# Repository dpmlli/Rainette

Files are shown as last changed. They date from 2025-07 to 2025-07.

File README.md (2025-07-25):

# Rainette

The ***Rainette*** project carried out as part of the Bachelor thesis at HEIG-VD. The
project involves designing an electronic board capable of collecting measurements
and controlling actuators to regulate an aquaponic greenhouse. It is an embedded
system that communicates wirelessly with a central unit and can operate on battery
power. The work includes the phases of preliminary analysis, hardware and software
design, as well as commissioning.

## Content

The repository contains 3 folders: `DOC`, `HW`, and `SW`.

- **DOC** : contains the project documentation. This includes :
    * Some elements specific to the *Rainette* PCB
    * The final report and the specifications
    * The logbook and planning documents
- **HW**  : contains the *Altium* projects for the *Rainette* and *STM32WB5MM-DK* boards.
- **SW**  : contains all the project code. This includes :
    * The firmware for the *Rainette* and *Disco (STM32WB5MM-DK)* boards
    * The programs for the *Raspberry Pi*
    * The simulation scripts

## Script instructions

### Mbed OS

To set up the code for the *Rainette* and *Disco* boards :
- Retrieve the contents of the `Mbed OS` folder and add the `mbed-os` folder from the following repository: https://github.com/ARMmbed/mbed-os. To reproduce the environment in which the project was developed, the following *VSCode* extensions must be installed : `C/C++ Tools`, `Task Runner`, `Cortex-Debug`, and `Copy file name`. You also need to install Mercurial, Mbed CLI, and the dependencies listed in the `requirements.txt` file. More details here : https://github.com/YannCharbon/vscode-mbed-env.  
- Then add the files from either the `Rainette` or `Disco` folders.
- Update the firmware of the Cortex-M0+ using the `STM32CubeProgrammer` software. Use the binary `stm32wb5x_BLE_HCILayer_fw.bin`, version 1.12.0 (additional instructions can be found in the report).
- Compile the program.
- For the *Disco* board, the binary can be flashed directly from *VSCode*. With the *Rainette* board, it must be done using the `STM32CubeProgrammer` software following these steps :
    1. Connect to the board
    2. *FUS* tab: Update the firmware using the following binary `stm32wb5x_BLE_HCILayer_fw.bin`, version 1.12.0 (`M0+ FW` folder)
    3. *FUS* tab: Click the `Start Wireless Stack` button
    4. *Erasing & Programming* tab: Start programming using the *Rainette* binary

### GUI

The `rainette_GUI.py` and `disco_GUI.py` scripts require the following Python libraries: `bleak` and `pyside6`. Python version 3.11 was used, but the scripts should work with earlier versions as well.

Once *advertising* is enabled by the *BLE* server, wait 2–3 seconds before running the script. The window will appear if the server is successfully detected by the client.

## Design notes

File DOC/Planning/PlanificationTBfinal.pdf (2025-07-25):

Étapes | Tâches
Échéances
Début du projet | Analyse fonctionnelle du projet, recherches sur le sujet Planification Définition du cahier des charges

Hardware
Objectifs, contraintes, choix principaux, budget

Schéma : connexions externes

Schéma : analyse fonctionnelle

Schéma : choix des composants

Schéma : finalisation

PCB : placement des composants

PCB : routage

PCB : assemblage et dépannage

## Planification TB Pomelli

Software
Module : communications entre les devkits

Module : prise en main et installation bibliothèques

Modules : tests individuels des éléments

Modules : programmation du main et dépannage

Rapsberry PI : prise en main et installation bibliothèques

Raspberry PI : programmation du main et dépannage

Tests et validation
Tests entre modules et Raspberry PI

Heures planifiées
Heures effectuées

Heures (plan./effe.) | Semaine 1 | Semaine 2 | Semaine 3 | Semaine 4 | Semaine 5
| | | ven. 7.3
| | | CdC
35 | | | FIN | | C

### 28 R 30 U 4 N 2 C 4 H

3
168

### 12 C 15 R 12 U 3 N 24 C 20 H

24
40

### 24 C 49 R 12 U 20 N 24 C 18 H

24

Février | Mars

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
Semaine 6 | Semaine 7 | Semaine 8 | Semaine 9 | Vacances | Semaine 10 | Semaine 11

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
Avril

PÂQUESPÂQUES

Semaine 12 | Semaine 13 | Semaine 14 | Semaine 15 | Semaine 16 | Semaine 17 | Semaine 18
| | | | ven. 13.6 Rendu inter.

FIN

Mai | Juin

Semaine 19 | Semaine 20 | Semaine 21 | Semaine 22 | Semaine 23 | Semaine 24 | Semaine 25
| | | ven. 25.7 Rendu fin.
Juillet | Août

FIN

FIN

Semaine 26 Semaine 27
lun. 18.8
Affiche

Août

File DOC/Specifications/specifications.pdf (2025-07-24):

## Module de commande de serre aquaponique Cahier des charges - Version 0

### Damien Pomelli

### March 27, 2025

## 1 Descriptif

Le projet consiste en la réalisation d’éléments électroniques permettant l’automatisation et la surveillance d’une serre aquaponique ou hydronique. Ce type de serre est composé d’un circuit d’eau fermé pouvant contenir un écosystème, raison pour laquelle il est nécessaire de pouvoir mesurer les grandeurs physiques cruciales telles que la température de l’eau ou le taux de pH.
Le travail de Bachelor se compose en deux grandes phases. La première consiste en la réalisation d’une carte électronique capable de collecter des données de différents capteurs et de pouvoir les envoyer vers une unité centrale. Cette carte doit pouvoir fonctionner sur pile et/ou par alimentation filaire. La communication avec l’unité centrale doit se faire au moyen d’un protocole sans fil. Le développement de la carte doit être axé sur la basse consommation pour le fonctionnement sur pile. La carte doit être capable de lire des valeurs analogiques au moyen d’un ADC mais elle ne contient pas d’interface spécifique à une sonde en particulier. La carte doit également être en mesure de piloter des actionneurs.
La seconde partie du travail est dédiée à la programmation de cette carte. Elle doit être en mesure de transmettre les données récoltées par les capteurs et d’activer des actionneurs si une commande lui est transmise. Il est également demandé de programmer l’unité centrale afin qu’elle puisse communiquer avec la/les carte/s électroniques. Il n’est pas prévu de réaliser la gestion globale de la serre sur l’unité centrale, simplement de s’assurer que la communication fonctionne correctement.

1

## 2 Objectifs

Les objectifs de ce projet sont les suivants :

- Mener le projet en documentant l’avancement. Identifier et expliquer les raisons et solutions à apporter en cas d’incapacité à remplir un objectif fixé.
- Concevoir une carte électronique sous forme de prototype selon les critères suivants.
1. Doit pouvoir fonctionner sur pile et/ou par alimentation filaire.
2. Doit pouvoir collecter des données provenant d’un capteur.
3. Doit pouvoir piloter un élément (ex: GPIO, relai, LED).
4. Doit pouvoir lire une tension analogique.
- Programmer la carte électronique selon les critères suivants.
5. Doit pouvoir communiquer sans fil.
6. Doit pouvoir transmettre une donnée.
7. Doit pouvoir recevoir une donnée.
- Programmer l’unité centrale selon les critères suivants.
8. Doit pouvoir communiquer sans fil.
9. Doit pouvoir transmettre une donnée.
10. Doit pouvoir recevoir une donnée.

## 3 Contraintes

Le projet doit respecter les règles fixées par la HEIG-VD pour les travaux de Bachelor, notamment en ce qui concerne :

- Le budget alloué.
- Le temps imparti.
- Les ressources disponibles.

## 4 Livrables

Les livrables attendus pour ce projet sont :

- Rapport du projet : version intermédiaire au milieu du projet et version finale en fin de projet.
- Carte électronique : prototype fonctionnel selon les critères fixés.
- Code source de la carte électronique : selon les critères fixés.
- Code source de l’unité centrale : selon les critères fixés.
- Documentation détaillant le fonctionnement (si non inclus dans le rapport).

2

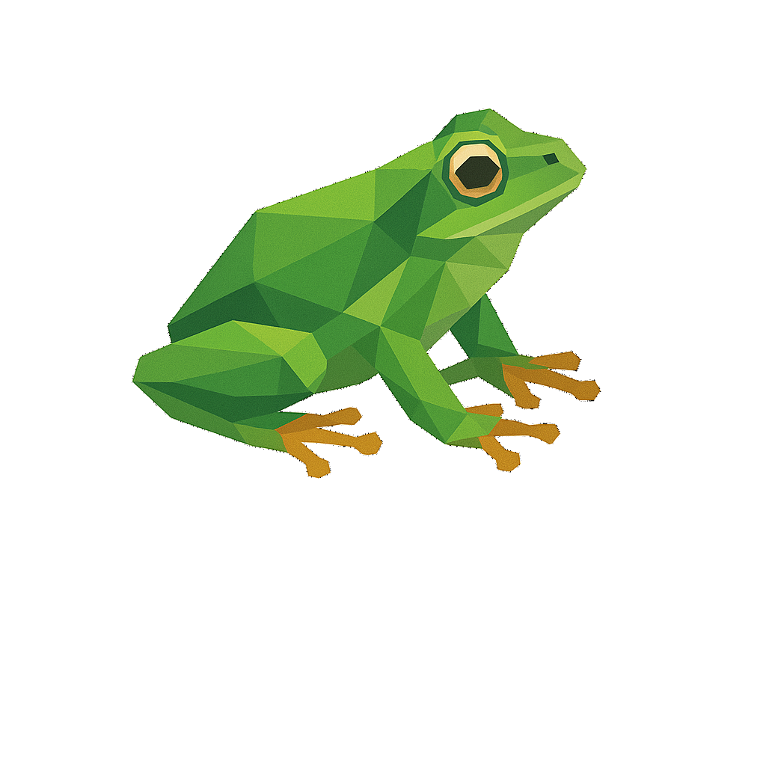
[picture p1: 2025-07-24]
DOC/images/Rainette_low_poly_transp.png

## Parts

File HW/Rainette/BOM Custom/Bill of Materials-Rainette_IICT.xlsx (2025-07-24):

Designator | Quantity per PCB | Total Quantity | Manufacturer_Part_Number | Manufacturer_Name | Mouser Part Number | DigiKey Part Number | Website URL
D5 | 1 | 3 | RS2DFL | Taiwan Semiconductor Corporation |  | 1801-RS2DFLCT-ND
D6 | 1 | 3 | 824500331 | Wurth Elektronik | 710-824500331
D29, D30, D31 | 3 | 9 | MMSZ5227BT1G | onsemi | 863-MMSZ5227BT1G
F1 | 1 | 3 | 0ZCK0075FF2E | Bel Fuse | 530-0ZCK0075FF2E
J1 | 1 | 3 | UJC-HP-G-5-SMT-TR | Same Sky | 179-UJCHPG5SMTTR
J5, J6 | 2 | 6 | PH1RB-03-UA | Adam Tech | 737-PH1RB-03-UA
J10 |  | 1 | TC2050-IDC | Tag-Connect LLC |  | TC2050-IDC-ND
PS1 | 1 | 3 | TSR 1-2450E | Traco Power | 495-TSR1-2450E
X1, X2 | 2 | 6 | PH1-02-UA | Adam Tech | 737-PH1-02-UA
 |  | 1 | KIT-304 | Atlas Scientific |  | 5016-KIT-304-ND | https://atlas-scientific.com/kits/surveyor-rtd-analog-kit/

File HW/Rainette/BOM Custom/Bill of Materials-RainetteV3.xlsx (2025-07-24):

Designator | LibRef | Footprint | Quantity | Manufacturer_Part_Number | Manufacturer_Name | Mouser Part Number | DigiKey Part Number | Farnell Part Number
C1, C2, C3, C10, C12 | CMP-0001778-4 | CAPC3216X18N | 5 | CL31B106KBHNNNE | Samsung Electro-Mechanics | 187-CL31B106KBHNNNE
C4, C6, C7, C8, C9, C11, C13, C14 | CMP-0003371-1 | CAPC1005X05N | 8 | GCM155L8EH104KE07D | Murata Electronics | 81-GCM155L8EH104KE7D
C5 | CMP-0003402-1 | CAPC1005X05N | 1 | GCM155R71H102MA37D | Murata Electronics | 81-GCM155R71H102MA7D
D1, D4 | CMP-0002421-1 | SODFL250X110-2N | 2 | CDSOD323-T08SC | Bourns | 652-CDSOD323-T08SC
D2 | CMP-0005477-4 | SOD3717X135 | 1 | MMSZ5233BT1G | onsemi |  | MMSZ5233BT1GOSCT-ND
D3 | CMP-0001774-4 | SODFL371X135-2N | 1 | MBR0540-TP | Micro Commercial Components | 833-MBR0540-TP
D7, D8, D9, D10, D12, D14, D15, D16, D17, D18, D19, D20, D21, D26, D27, D28 | PESD3V3L1BSLZ | PESD3V3L1BSLZ | 16 | PESD3V3L1BSLZ | Nexperia | 771-PESD3V3L1BSLZ
D11, D13 | CMP-0002115-5 | LTST-C171 | 2 | LTST-C171KRKT | LITEON | 859-LTST-C171KRKT
IC1, IC9 | G3VM-61VY3_TR_ | G3VM61VY3TR | 2 | G3VM-61VY3(TR) | Omron Electronics | 653-G3VM-61VY3TR
IC3 | TPS63001DRC | TPS63002DRCT | 1 | TPS63001DRC | Texas Instruments
IC4, IC5, IC6, IC8 | XC8102AA01MR-G | SOT95P280X130-5N | 4 | XC8102AA01MR-G | Torex | 865-XC8102AA01MR-G
IC7 | VEML6030 | VEML6030 | 1 | VEML6030 | Vishay | 78-VEML6030
J3, J4, J7, J8, J9 | 1729128 | 1729128 | 5 | 1729128 | Phoenix Contact | 651-1729128
J12 | M20-9990345 | HDRV3W64P0X254_1X3_762X254X864P | 1 | M20-9990345 | Harwin | 855-M20-9990345
L1 | LPS3015-222MLB | LPS3015 | 1 | LPS3015-222MLB | COILCRAFT | 994-LPS3015-222MLB
P1 | 61300621121 | 61300621121 | 1 | 61300621121 | Wurth Elektronik |  | 732-5295-ND
Q1 | DMC3071LVT-13 | SOT95P280X100-6N | 1 | DMC3071LVT-13 | Diodes Incorporated | 621-DMC3071LVT-13
R1 | CMP-0004701-2 | RESC1005X04N | 1 | RL0402FR-070R1L | YAGEO | 603-RL0402FR070R1L
R2 | CMP-0004445-2 | RESC1608X04N | 1 | RT0603BRD07100KL | YAGEO |  |  | RT0603BRD07100KL
R3 | CMP-0004081-2 | RESC1005X04N | 1 | RT0402BRD0722KL | YAGEO | 603-RT0402BRD0722KL
R4 | CMP-0006715-1 | RESC3216X06N | 1 | RC1206FR-0782KL | YAGEO | 603-RC1206FR-0782KL
R5, R6 | CMP-0005383-3 | RESC2012X05N | 2 | RT0805BRD07120RL | YAGEO | 603-RT0805BRD07120RL
R7, R8 | CMP-0001959-3 | RESC1608X04N | 2 | RC0603FR-07220RL | YAGEO | 603-RC0603FR-07220RL
R9, R10 | CMP-0004349-2 | RESC1608X04N | 2 | RT0603BRD0710KL | YAGEO | 603-RT0603BRD0710KL
R11, R12, R13, R14, R15 | CMP-0001940-3 | RESC1608X04N | 5 | RC0603FR-0722RL | YAGEO | 603-RC0603FR-0722RL
S1, S2 | CMP-00001-2 | PTS645SL43SMTR92LFS | 2 | PTS645SL43SMTR92 LFS | C&K |  | CKN10880CT-ND
TP7, TP8, TP9, TP10, TP11 | CMP-0002617-2 | 5117 | 5 | 5117 | Keystone Electronics | 534-5117
U1 | STM32WB5MMGH6TR | SIP-LGA86_STM | 1 | STM32WB5MMGH6TR | STMicroelectronics | 511-STM32WB5MMGH6TR
U2 | SHT41-AD1B-R2 | DFN4_SHT41_SEN | 1 | SHT41-AD1B-R2 | Sensirion | 403-SHT41-AD1B-R2

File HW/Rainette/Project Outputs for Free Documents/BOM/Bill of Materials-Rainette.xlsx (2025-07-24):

Designator | LibRef | Footprint | Library Name | Quantity | Supplier 1 | Supplier Part Number 1 | Supplier Unit Price 1 | Supplier 2 | Supplier Part Number 2 | Supplier Unit Price 2
C1, C2, C3, C10, C12 | CMP-0001778-4 | CAPC3216X18N | HEIG-VD Pro | 5
C4, C6, C7, C8, C9, C11, C13, C14 | CMP-0003371-1 | CAPC1005X05N | HEIG-VD Pro | 8
C5 | CMP-0003402-1 | CAPC1005X05N | HEIG-VD Pro | 1
D1, D4 | CMP-0002421-1 | SODFL250X110-2N | HEIG-VD iAi | 2
D2 | CMP-0005477-4 | SOD3717X135 | HEIG-VD Pro | 1
D3 | CMP-0001774-4 | SODFL371X135-2N | HEIG-VD Pro | 1
D5 | CMP-0002644-1 | SODFL375X120-2N | HEIG-VD iAi | 1
D6 | CMP-0005814-3 | DIOM4227X25N | HEIG-VD iAi | 1
D7, D8, D9, D10, D12, D14, D15, D16, D17, D18, D19, D20, D21, D26, D27, D28 | PESD3V3L1BSLZ | PESD3V3L1BSLZ | Rainette.SchLib | 16
D11, D13 | CMP-0002115-5 | LTST-C171 | HEIG-VD Pro | 2
D29, D30, D31 | CMP-0005471-4 | SOD3717X135 | HEIG-VD iAi | 3
F1 | CMP-0002366-7 | RESC2012X05N | HEIG-VD Pro | 1
IC1, IC9 | G3VM-61VY3_TR_ | G3VM61VY3TR | Rainette.SchLib | 2
IC3 | TPS63001DRC | TPS63002DRCT | Rainette.SchLib | 1
IC4, IC5, IC6, IC8 | XC8102AA01MR-G | SOT95P280X130-5N | Rainette.SchLib | 4
IC7 | VEML6030 | VEML6030 | Rainette.SchLib | 1
J1 | UJC-HP-G-5-SMT-TR | UJCHPG5SMTTR | Rainette.SchLib | 1
J2 | CMP-0002595-4 | CONN HEADER VERT 6POS 2.54MM 61300621121 | HEIG-VD Pro | 1
J3, J4, J7, J8, J9 | 1729128 | 1729128 | Rainette.SchLib | 5
J5, J6 | PH1RB-03-UA | HDRRA3W64P0X254_1X3_762X250X301P | Rainette.SchLib | 2
J10 | TC2050-IDC | TC2050-IDC | Rainette.SchLib | 1
J12 | M20-9990345 | HDRV3W64P0X254_1X3_762X254X864P | Rainette.SchLib | 1
L1 | LPS3015-222MLB | LPS3015 | Rainette.SchLib | 1
PS1 | TSR_1-2450E | TSR12450E | Rainette.SchLib | 1
Q1 | DMC3071LVT-13 | SOT95P280X100-6N | Rainette.SchLib | 1
R1 | CMP-0004701-2 | RESC1005X04N | HEIG-VD iAi | 1
R2 | CMP-0004445-2 | RESC1608X04N | HEIG-VD Pro | 1
R3 | CMP-0004081-2 | RESC1005X04N | HEIG-VD iAi | 1
R4 | CMP-0006715-1 | RESC3216X06N | HEIG-VD iAi | 1
R5, R6 | CMP-0005383-3 | RESC2012X05N | HEIG-VD Pro | 2
R7, R8 | CMP-0001959-3 | RESC1608X04N | HEIG-VD Pro | 2
R9, R10 | CMP-0004349-2 | RESC1608X04N | HEIG-VD Pro | 2
R11, R12, R13, R14, R15 | CMP-0001940-3 | RESC1608X04N | HEIG-VD Pro | 5
S1, S2 | CMP-00001-2 | PTS645SL43SMTR92LFS | HEIG-VD Pro | 2
TP7, TP8, TP9, TP10, TP11 | CMP-0002617-2 | 5117 | HEIG-VD Pro | 5
U1 | STM32WB5MMGH6TR | SIP-LGA86_STM | STM32WB5MMGH6TR.SchLib | 1
U2 | SHT41-AD1B-R2 | DFN4_SHT41_SEN | SHT41-AD1B-R2.SchLib | 1
X1, X2 | CMP-0002184-3 | CONN HEADER VERT 2POS 2.54MM | HEIG-VD Pro | 2

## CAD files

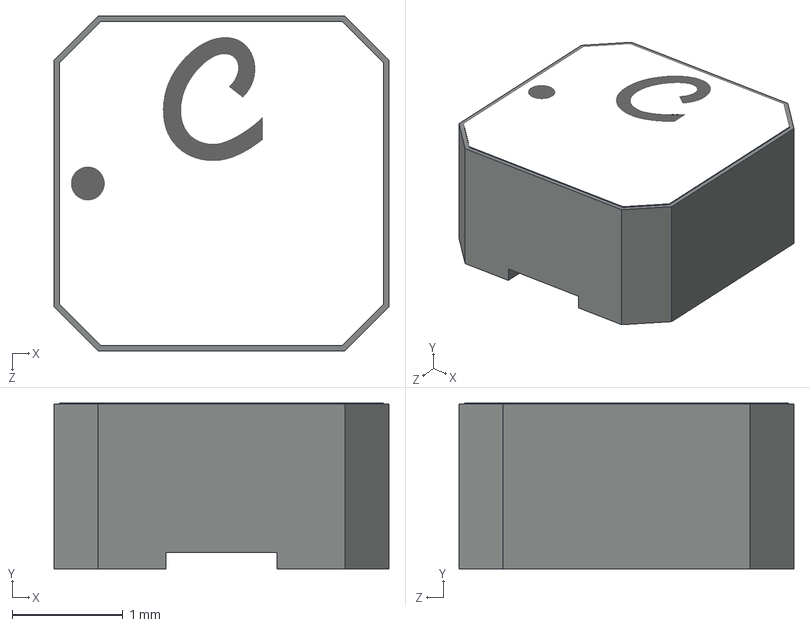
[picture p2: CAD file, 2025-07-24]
HW/Rainette/Imported 3D files/LPS3015-222MRC.stp
3.03 x 1.50 x 3.03 mm

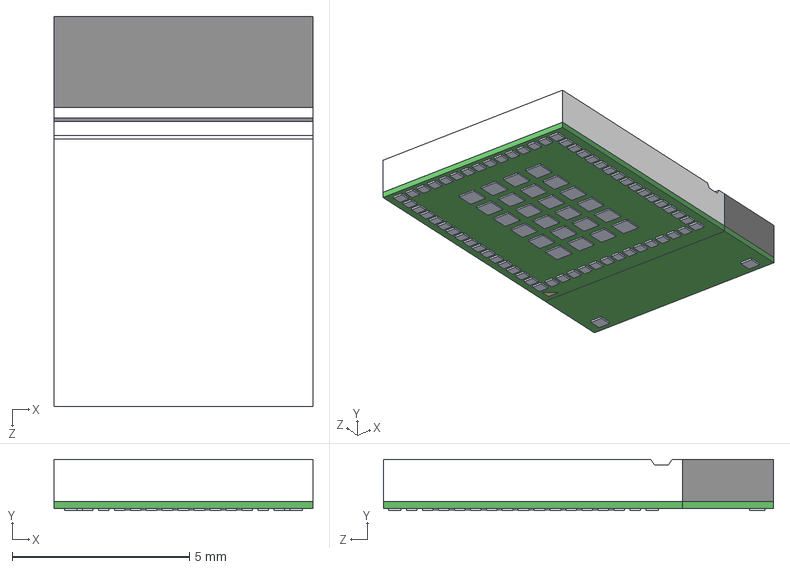
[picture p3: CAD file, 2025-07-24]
HW/Rainette/Imported 3D files/STM32WB5MMGH6TR.stp
7.30 x 1.44 x 11.0 mm
STM32WB5MMGH6TR_3
STM32WB5MMGH6TR_37
STM32WB5MMGH6TR_72
STM32WB5MMGH6TR_6
STM32WB5MMGH6TR_71
STM32WB5MMGH6TR_69
STM32WB5MMGH6TR_56
STM32WB5MMGH6TR_61
STM32WB5MMGH6TR_87
STM32WB5MMGH6TR_36
STM32WB5MMGH6TR_43
STM32WB5MMGH6TR_9
STM32WB5MMGH6TR_2
STM32WB5MMGH6TR_90
STM32WB5MMGH6TR_38
STM32WB5MMGH6TR_52
STM32WB5MMGH6TR_21
STM32WB5MMGH6TR_5
STM32WB5MMGH6TR_39
STM32WB5MMGH6TR_24
STM32WB5MMGH6TR_40
STM32WB5MMGH6TR_73
STM32WB5MMGH6TR_78
STM32WB5MMGH6TR_22
STM32WB5MMGH6TR_59
STM32WB5MMGH6TR_80
STM32WB5MMGH6TR_19
STM32WB5MMGH6TR_65
STM32WB5MMGH6TR_68
STM32WB5MMGH6TR_11
STM32WB5MMGH6TR_48
STM32WB5MMGH6TR_74
STM32WB5MMGH6TR_64
STM32WB5MMGH6TR_20
STM32WB5MMGH6TR_16
STM32WB5MMGH6TR_13
STM32WB5MMGH6TR_49
STM32WB5MMGH6TR_46
STM32WB5MMGH6TR_31
STM32WB5MMGH6TR_30
STM32WB5MMGH6TR_85
STM32WB5MMGH6TR_81
STM32WB5MMGH6TR_66
STM32WB5MMGH6TR_83
STM32WB5MMGH6TR_15
STM32WB5MMGH6TR_53
STM32WB5MMGH6TR_89
STM32WB5MMGH6TR_32
STM32WB5MMGH6TR_17
STM32WB5MMGH6TR_45
STM32WB5MMGH6TR_75
STM32WB5MMGH6TR_62
STM32WB5MMGH6TR_27
STM32WB5MMGH6TR_76
STM32WB5MMGH6TR_34
STM32WB5MMGH6TR_54
STM32WB5MMGH6TR_67
STM32WB5MMGH6TR_88
STM32WB5MMGH6TR_29
STM32WB5MMGH6TR_86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

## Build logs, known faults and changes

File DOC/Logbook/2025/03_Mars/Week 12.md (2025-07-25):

# Semaine 12, du lundi 24.03 au dimanche 30.03 2025

## Résumé de la semaine

## Lundi 24.03

Semaine passée : CRUNCH. Visite d'une ferme aquaponique https://www.lafermeaquaponique.com/. Il en ressort que la plupart des capteurs (pH,DO,..) ne sont pas utiles sur le module, même pour les grandes installations. Peut-être faut il se contenter d'une sonde de température (PT1000 - https://files.atlas-scientific.com/PT-1000-probe.pdf). 

Réflexions sur la manière de lire une PT1000, contraintes de faible conso et de dynamique. Il faut étudier les montages différentiels étudiés en cours de Capteurs. Finalement, pas besoin de développer l'interface pour les ADC, on s'était mal compris sur le cahier des charges et le but du projet.

Commande de kits STM32WB5MM-DK pour tester la communication. Ce même kit est compatible ARM Mbed (https://os.mbed.com/platforms/DISCO-WB5MMG/). Recommandation de M. Favrat : partir du fichier Altium du Dev kit pour ne pas perdre trop de temps.

**Puissance sur la carte** Tension de fonctionnement du STM32 : entre 1V8 et 3V3

**LTC4412** Encore disponible mais cher.. 

Découverte de **SnapMagicSearch** : Librairie de composants gratuite.

Schémas ESD et fonctionnel sur draw.io

**STM32WB5MMG** Tableau 84 : Tension Vin analogique {0-VDDA} donc il faut prévoir des protections sur l'ADC (<3V3). Les interfaces Atlas Scientific fournissent une tension analogique de max 3V donc c'est bon pour cette usage mais attention aux autres capteurs !

## Mardi 25.03

## Mercredi 26.03

## Jeudi 27.03

Version 0 du cahier des charges transmis au professeur. Il faut ajouter le Gantt mais j'ai pas réussi à l'intégrer dans Latex.

**LTC4412** validé par un assistant. Faut pas s'emmerder pour un TB au niveau du prix.
Lien MOUSER (https://www.mouser.ch/ProductDetail/Analog-Devices/LTC4412IS6TRPBF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)
Autrement, un MOSFET mais c'est moins solide. 

Il faut se poser la question si c'est pertinent d'avoir un fuel gauge avec une pile. Après discussion avec un assistant, ce n'est pas le cas. On peut
relier la pile à l'ADC (attention à la plage min et max, idée : pont diviseur avec MOSFET). Les piles en série sont sensées se décharger en même temps.
Attention aussi à la référence de tension de l'ADC, il faut checker qu'il y ait un réf interne. Pour l'ADC, on utilisera le mode "single" car le mode
"différentiel" est utile contre le bruit mais là c'est en ordre.

Essais avec Altium, début des différentes sheets du projet.

Il faut remplir un coup le rapport.

Finalement, a-t-on vraiment besoin du LTC4412 ? C'est soit l'un soit l'autre donc on peut imaginer plus simple.

Comment merge plusieurs pdf avec LaTex : https://tex.stackexchange.com/questions/8662/merge-two-pdf-files-output-by-latex

## Vendredi 28.03

## Samedi 29.03

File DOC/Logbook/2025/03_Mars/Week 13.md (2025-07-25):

# Semaine 13, du lundi 31.03 au dimanche 06.04 2025

## Résumé de la semaine

## Lundi 31.03

## Mardi 01.04

Mesure de la tension de la pile : on pourrait envisager un montage à ampli-op pour mesurer la tension dans la bonne plage, cela éviterait de tirer trop de courant sur la pile avec un pont diviseur. Selon Wikipédia et GPT, pas de montage "classique" pour un gain positif et inférieur à 1. Il faudrait un pont diviseur avec un suiveur. Euh ⚠️attention⚠️ la tension d'entrée du suiveur doit être comprise dans la plage de l'alimentation ! Donc ça ne fonctionnerait pas si on met direct la tension de la pile en entrée.. 

Tout comme les disco-kit, on pourrait aussi simplement utiliser un jumper pour sélectionner la source d'alimentation (pile ou filaire) car les deux options ne sont pas amenées à se présenter en même temps.

Pour les relais, je ne trouve pas pertinent d'utiliser un gros relais pour driver du 230V, on va rester sur des **relais MOSFET** avec des tensions de charge "raisonnables".

Pour les régulateurs de tensions, on pourrait imaginer 3 LDO : 1 (3V3?) pour les éléments activés en permance (mode sleep), 1 3V3 pour les éléments activés pour les mesures ponctuels et 1 5V pour applications alimentées par fil. Les 2 derniers seraient (dés)activables pour les périodes de sommeil.

**Discussion avec M. Favrat** :
- Logic level shifter pas nécessaire, y'a pas vraiment d'interface 5V.
- Au lieu d'utiliser le régulateur 3V3 activable, utiliser des power switchs (schéma fourni) pour contrôler chaque élément.
- Régulateur 5V pas nécessaire à priori, pas d'usage.
- Mesure de la pile : pas besoin de suiveur, schéma fourni avec 2 MOSFETs et un pont diviseur.

⚠️ Important ⚠️ Il faut quand même vérifier que l'interface de chaque capteur ADC ne demande pas de 5V mais fonctionne avec du 3V3.

Toutes les interfaces de Atlas Scientific fonctionnent en 3V3. Les flotteurs sont de simples switchs, donc à priori pas de problème avec du 3V3.

Prévoir des protections de polarité.

Lire *Applied Embedded Electronics* pour trouver des points importants de la conception de carte.

Pourquoi pas ajouter un capteur de luminosité sur la carte (réf. intéressante trouvée).

Planification mise à jour.

Création d'une checklist pour robustesse du design électronique.

Module STM32 : pas besoin de quartz externe.

Travail et prise de notes sur Altium (librairies, sheet symbols,..)

## Mercredi 02.04

## Jeudi 03.04

## Vendredi 04.04

Est-ce qu'on met un step-down pour l'alim filaire ? Oui avec un autre connecteur que le 5V. Guide optique pour capteur de luminosité et leds.

Footprint du capteur de temp. modifié.

Trouver un nom, genre Frogy ou Rainette.

## Samedi 05.04

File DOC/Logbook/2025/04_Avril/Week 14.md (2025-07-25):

# Semaine 14, du lundi 07.04 au dimanche 13.04 2025

## Résumé de la semaine

## Lundi 07.04

## Mardi 08.04

Réception des Disco-kit pour le STM32WB5MMG. Le module est vraiment compact, il ne se brase pas à la main. 

Nom trouvé pour le projet : Rai**net**te

Justification de la diversité des éléments présents sur la carte : pour faire des essais et déterminer ce qui est pertinent en vrai et ce qui ne l'est pas.

Connecteurs 1729128 de Phoenix contact.

**REGULATEUR 1V8 ???** -> non pas besoin, c'est géré en interne.

Calcul de la consommation (p.86) 1 réveil chaque 10 minutes
- BLE : 10 sec @ 1mA -> moyenne = 16.6 uA (10/(10*60))
- Sondes ADC : 10 sec @ 3mA -> moyenne = 50 uA
- 

Installation du SamacSys Loader pour les footprints Altium.

`Ctrl + M` pour les mesures sur `.pcblib`

Footprint du connecteur 1729128 vérifié. Pareil pour le TSR_1-2450E.

Je choisis le G3VM-61VY3 pour piloter de grandes tensions car moins cher et 60V @ 700mA.

Il faut discuter des leds avec M. Favrat car grosse conso..

Tous les composants ajoutés aujourd'hui (y compris capteur de luminosité) ont été vérifiés.

## Mercredi 09.04

## Jeudi 10.04

## Vendredi 11.04

On continue, il faudrait pouvoir acheminer toutes les connexions requises vers le module aujourd'hui.

Pins LPUART et SPI ? -> plutôt USART

Connector ST-Link : Tag-connect "Connect the TC2050-IDC(-NL)-050-STDC14 to the ST-LINK V3 SET via the STDC14 connector."
Version "legged" : https://www.tag-connect.com/product/tc2050-idc-050-stdc14. 
Le STDC14 est le connecteur du ST-Link V3set. Info sur Datasheet St-Link tableau 8.1.2.

Sur CubeMX on trouve pas direct le SWD, il faut aller dans GPIO -> debug et sélectionner comme on veut. Le datasheet du STM32WB55xx indique que les pattes SW sont PA13 et PA14, elles sont déjà inclues avec le JTAG 5 pins.

Avant on avait les leds :
```
BLUE : Vf = 3V, If = 20mA.
Rb = (3.3-Vf)/If = 15 -> 18 Ohm

RED : Vf = 2V, If = 20mA.
Rr = (3.3-Vf)/If = 65 -> 68 Ohm
```
*If* trop important, on regarde le schéma du DK et on va abaisser *If*. 

Je retire la led bleue car la rouge consomme moins. On met *If* = 10mA => R = 120 Ohm

Les pull-up sont à mettre au centre, sans switchs pour l'alim.

Il faut terminer l'estimation de consommation pour le LDO.

## Samedi 12.04

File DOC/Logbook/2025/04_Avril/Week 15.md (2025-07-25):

# Semaine 15, du lundi 14.04 au dimanche 20.04 2025

## Résumé de la semaine

## Lundi 14.04

## Mardi 15.04

Calcul de la consommation (p.86) 1 réveil chaque 10 minutes
- BLE : 10 sec @ 1mA -> moyenne = 16.6 uA (10/(10*60))
- Icore Sleep : 740 uA (à vérifier/valider...)
- Sondes ADC : 10 sec @ 3mA -> moyenne = 50 uA
- Load Switch : 3.6 uA * nbr_de_switchs (4) = 14.4 uA -> dépend de l'utilisation
- Battery tester : négligeable ?
- Leds Duty Cycle 20% 10sec à chaque 10 minutes : 2* 10mA *0.2 * 10/(10*60) = 66.6 uA
- Lumi sensor : 45 uA * 10/(10*60) < 1uA
- Temp sensor : 320 uA * 10/(10*60) = 4 uA
- LDO 34 uA

- GPIO pull ups : 40kOhm (p.133)

LDO choisi (300 mA pour être large)

Travail sur le routage vers le MCU. L'absence du prof m'a fait débuté le rapport sur MarkDown.

REFLECHIR SUR LES GND ANA ET NUM !!!!!

## Mercredi 16.04

## Jeudi 17.04

## Vendredi 18.04

## Samedi 19.04

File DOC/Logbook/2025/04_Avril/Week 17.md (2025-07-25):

# Semaine 17, du lundi 28.04 au dimanche 04.05 2025

## Résumé de la semaine

## Lundi 28.04

## Mardi 29.04

Discussion avec M. Favrat
- utiliser un DC/DC au lieu du LDO car mauvaise performance sur batterie, ajouter une inductance
- 10uF autour du DC/DC, utile pour le reste si éloigné, 100nF seulement autour des IC mais pas du DC/DC, 2 condos en parallèle pour ESR
- Schottky OK pour batterie, diode simple pour High DC. 
- TVS Bidirectionnelles avec seuil adapté et attention ESR, Normes IEC serres !!
- Transistors back to back : c'est un seul composant.
- STM32 : 100nF pour chaque patte sauf 4 et 6 regroupées
- on suppprime la résistance de pull up du capteur de luminosité car il y en a déjà à dispo sur la GPIO.
- pas de protections sur les optocoupleurs
- calculer les pull up de l'I2C avec RC
- SPI et USART limités en usage externes (exemple de la Flash SPI), il faut calculer et limiter le baud rate (1 MHz)
- Pas de protections pour le ST Link
-Définir si pull up pour le SPI

Sur la fin, mise en place des TVS 3V3.

## Mercredi 30.04

## Jeudi 01.05

## Vendredi 02.05

Selon le datasheet du STM32WB55XX, pas besoin de pull up externe sur le signal NSS (Slave Select) car on peut congigurer une pull up interne. Je supprime donc la résistance initialement placée.

Renommez les composants : 
...

Importer les composants du schéma au PCB :
...

Les TVS comportent des erreurs car le symbôle est *off grid*.

Pour le rapport, on met juste le *résultat final* pas les 15 étapes qui précèdent.

Début du placement des composants sur le PCB.

## Samedi 03.05

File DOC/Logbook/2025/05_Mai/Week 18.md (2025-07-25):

# Semaine 18, du lundi 05.05 au dimanche 11.05 2025

## Résumé de la semaine

## Lundi 05.05

## Mardi 06.05

On peut modifier les règles (Error, Warning,..) dans Project -> Projet Options -> Error reporting.

J'ai passé les Off grid restantes en No report après avoir modifié le symbole des TVS.
J'ai également retiré l'erreur qui indique les multiples noms, mais ça ne permet pas pour autant de régler le problème du GND qui n'apparait pas sur le PCB.

Problème des GND à priori résolu. Il fallait aller dans Project -> Project options -> Options et dans `Net Identifier Scope` passer de `Strict Hierarchical` à `Hierarchical`. 

| Mode | Ports & Sheet Entries obligatoires | Power Ports globaux | Net Labels globaux | 
| --- | --- | --- | --- |
| **Hierarchical** | ✅ Oui | ✅ Oui | ❌ Non | 
| **Strict Hierarchical** | ✅ Oui | ❌ Non | ❌ Non | 
| **Global** | ❌ Non | ✅ Oui | ✅ Oui | 

Un premier Design Rules Check relève plusieures erreurs, notamment la hauteur du 3D body du connecteur STLink. Il y a surtout des erreurs pour le `Minimum Solder Mask Sliver` ce qui implique de vérifier avec Eurocircuits. 

Finalement, après discussion avec le prof, ce n'est pas à faire directement. Il faut en revanche remplacer le footprint du connecteur USB pour prendre du SMD. 

On peut concevoir de nouveaux vias dans `Design` -> `Layer Stack Manager` -> `Via Types`, mais ce n'est pas comme ça qu'on va le faire.
On crée une bibliothèque de via dans File -> New -> Library -> Via. On peut ensuite faire clique droit sur la fenêtre et ajouter un via, puis le dimensionner.

On a récupéré le projet Altium du Disco Kit, les vias du côté du module sont des blind1:2 -> classe de prix plus élevée. On essaie de faire sans.

Il faut mettre les signaux sur la périphérie du module pour éviter ces vias.

Pas de blind dispo pour le prototypage Eurocircuits : https://www.eurocircuits.com/services/pcb-proto/.

Pour mettre le maximum de signaux sur les bords, `EN_LUMI_SENS` et `EN_TEMP_SENS` sont déplacés des pattes PC8 et PC9 aux pattes PB0 et PB1. Les signaux `GPIO_FLOAT_OUT` et `GPIO_FLOAT_IN` sont déplacés des pattes PD2 et PD3 aux pattes PB10 et PB11. Il ne reste plus que le GND patte 84.

Les pattes de communication ont été validées avec STMCubeMX, les pattes SPI ne sont pas les premières proposées, il faut modifier le routage manuellement.

Changement de connecteur USB-C pour utiliser du SMD. 

Simulation de Vadc(Vbatt)

Ajout de diode Zener 3.6V pour protéger l'ADC. 

Dimensionnement des résistances pour la mesure de la batterie.

## Mercredi 07.05

## Jeudi 08.05

Architecture proposée par GPT (pas oublier la gestion du Sleep et des différents paramétrages )

```
/root_project/
│
├── main.cpp                        <-- Point d'entrée principal
├── mbed_app.json                  <-- Configuration spécifique (ex: BLE, logs, traces, RTOS)
│
├── /include/
│   ├── I2CDeviceManager.h         <-- Interface pour gérer des périphériques I2C
│   ├── BLEManager.h               <-- Interface BLE (GATT, pub, sub)
│   ├── GPIOManager.h              <-- Contrôle GPIO (entrée/sortie)
│   ├── ADCReader.h                <-- Gestion des entrées analogiques
│
├── /src/
│   ├── I2CDeviceManager.cpp       <-- Implémentation des capteurs I2C (ex: TMP102, MPU6050)
│   ├── BLEManager.cpp             <-- Implémentation BLE (serveur/client GATT)
│   ├── GPIOManager.cpp            <-- Implémentation GPIO
│   ├── ADCReader.cpp              <-- Implémentation ADC
│
├── /services/
│   └── AppController.cpp          <-- Logique métier : coordonne les modules ci-dessus
│
├── /events/
│   └── EventQueueHandler.cpp      <-- EventQueue/Thread (pour décharger le main)
│
└── /utils/
    └── Logger.h/.cpp              <-- Utilitaire de debug/log simple (printf ou BLE logs)
```

## Vendredi 09.05

Discussion avec M. Favrat, Hochet et Charbon :
- Pas de cuivre sous l'antenne ! Il faut donc remanier les pistes.
- Ajouter au moins l'UART pour afficher des éléments sur la console.
- On peut éditer le via dans le PvLib en décochant *From Rule* -> *Relief* à *Direct* pour éviter les freins thermiques.
- PCBway : Instant Quote, même prix avec ces choix 
    - Piste/espacement minimum : 4/4 mil = 0,1016 mm / 0,1016 mm
    - Taille de trou minimum : 0,2 mm
- Tag Connect : Utiliser la référence du laboratoire pour ne pas devoir racheter un nouveau connecteur.
- Dans le *Layer Stack Manager*, on peut définir les couches : *Signal* -> le cuivre est en couleur, *Plane* -> le cuivre est invisible.
- Shift + S : isoler la couche sélectionnée.
- Placer des headers GND et VCC pour dépanner.

Il faut vérifier les positionnements décrits dans les datasheets (MCU, IC,..)

## Samedi 10.05

À mettre dans le glossaire :
- PCB = objet physique.
- Layout = fichier de conception (ou étape dans la conception).

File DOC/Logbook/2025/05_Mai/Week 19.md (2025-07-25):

# Semaine 19, du lundi 12.05 au dimanche 18.05 2025

## Résumé de la semaine

## Lundi 12.05

## Mardi 13.05

À priori, seuls le MCU et le DC/DC converter 3V3 possèdent une recommandation de layout.

Aïe, le datasheet du STM32 recommande de laisser une large surface de plan de masse à droite et de passer les signaux en bas.
Ca impliquerait de tout recommencer et d'utiliser d'autres vias.

Après discussion avec M. Favrat, on va juste passer les pistes de droite sur le bottom pour laisser un plan de masse sur le top. On peut garder 
le ST-Link à commander.

Le convertisseur DC/DC oscille autour des 1.5 MHz donc on ne risque pas de perturber l'ADC pour mesurera à des fréquences inférieures. On peut en revanche
élaborer des filtres RC pour couper les hautes fréquences (faut juste estimer la fréquence de l'ADC). Pour ça, on rajoute une résistance pour bien définir la valeur de tau.

Routage des signaux, c'est pas mal mais il faut continuer en disposant les composants et la sériegraphie.

## Mercredi 14.05

## Jeudi 15.05

## Vendredi 16.05

Gamme min de tension analogique à lire : 0-420mV (DO) et 1.058-1.3 (temp)
L'ADC possède 12 bits de résolution -> pas de 805uV donc suffisant selon moi sans devoir ajuster Vref+.

## Samedi 17.05

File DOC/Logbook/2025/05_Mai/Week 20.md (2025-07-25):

# Semaine 20, du lundi 19.05 au dimanche 25.05 2025

## Résumé de la semaine

## Lundi 19.05

## Mardi 20.05

#### Dimensionnement des résistances de pull-up

Longueur max de SCL : 43 mm
Longueur max de SDA : 44 mm

Demander
- Trous de fixation
- I2C pull up
- Plan de masse (polygon)
- Design rules

Connecter pattes à la masse
FR4 epoxy
0201 100nF non ok

Mettre les pattes en ANALOG pour passer avec la masse.
10k OK pour pull up

## Mercredi 21.05

## Jeudi 22.05

## Vendredi 23.05

M2 -> M2.5 min (idéalement M3)
Plan de masse sur tout le *Top*
Pas de GND sur GPIO (si vrm, VCC mais pas GND)
Connecter les condos sur schéma
Pas de freins thermiques sur les vias de stitching
On a réduit la taille des pads du module.
On peut laisser les pistes des GPIO sur le *Bottom*

Revoir l'estimation du courant, avec les différents modes du MCU
*Icore* plus grand en vitesse de croisière

Faut regarder sur GitHub/VSCode ce que font les modes SLEEP, DEEP SLEEP, .. (ouvrir avec CodeSpace)

Longueur de piste/plan < lambda/4 ou moins. Plus c'est petit et moins on atteint le sommet de la sinusoïde (explication Yann).

Il faut encore mettre des vias de stitching

## Samedi 24.05

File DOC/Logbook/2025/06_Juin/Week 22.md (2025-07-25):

# Semaine 22, du lundi 02.06 au dimanche 08.06 2025

## Résumé de la semaine

## Lundi 02.06

## Mardi 03.06

Pour étendre le solder mask de 0,02mm -> 0.786mil je passe la couche solder mask en rectangular pour passer des dimensions 13.78mil à 12.2mil
et de 11.81mil à 10.23mil

### Mode pile
Chaque 10 minutes :
- Réveil
- Mesure temp sensor
- Mesure lum sensor
- (Mesure pile)
- Mesure sondes
- Envoi BLE
- Dodo

### Mode fil
Chaque 10 minutes :
- Mesure temp sensor
- Mesure lum sensor
- (Mesure pile)
- Mesure sondes
- Envoi BLE

En permanence :
- Écoute BLE -> exécution
- Lecture/écriture GPIO

### Étapes programmation
1. Pouvoir debug la carte, installation de Mbed OS
2. Allumer les leds, lire les GPIO
3. ADC
4. I2C
5. BLE

BOM modifiée à la main

**Prompt BLE**
Tu es un expert en BLE. Je dois programmer une petite carte qui fonctionne soit sur batterie, auquel cas et ne fait qu'émettre ses mesures à un raspberry pi, soit sur fil et là en plus des mesures chaque x minutes elle peut aussi recevoir des ordres de la part du raspberry. Si on est sur batterie, on s'éveille juste pour envoyer les mesures et on se rendort, dans l'autre cas la consommation n'est pas un problème dans un peut rester attentif pour recevoir des infos. Je vais utiliser Mbed OS sur la petite carte. Que me proposes-tu pour mettre en place cette configuration ?

🔹 Périphérique BLE (ta carte) = GATT Server
Fournit un Service Mesures (e.g., température, humidité, etc.).
Une caractéristique de lecture/notification : le Raspberry lit ou s’abonne.
En mode filaire : ajoute une caractéristique de commande en écriture.

🔸 Raspberry Pi = GATT Client
Se connecte.
Lit ou reçoit les notifications.
Envoie des commandes en mode filaire via écriture.

| Élément | Description |
| --- | --- |
| **Service** | Regroupe plusieurs caractéristiques liées à une fonction  |
| **Caractéristique** | Contient une donnée (valeur), avec des propriétés d’accès |

Une caractéristique peut permettre différentes opérations, selon les propriétés qui lui sont attribuées. Les principales sont :

| Propriété | Sens de communication | Description |
| --- | --- | --- |
| **Read** | Périphérique → Centrale | La centrale (ex: smartphone) peut lire la valeur. |
| **Write** | Centrale → Périphérique | La centrale peut écrire une nouvelle valeur. |
| **Notify** | Périphérique → Centrale (push) | Le périphérique envoie automatiquement une mise à jour. |
| **Indicate** | Périphérique → Centrale (ack)  | Comme Notify, mais avec accusé de réception. |
| **Write Without Response** | Centrale → Périphérique | Écriture rapide, sans réponse nécessaire. |

| Rôle | Description |
| --- | --- |
| **Centrale** | L’appareil qui **initie** la connexion. Il **scanne** les périphériques BLE (ex : smartphone). |
| **Périphérique** | L’appareil qui **annonce** sa présence (advertising) et **attend** une connexion (ex : capteur, montre connectée). |

| Rôle | Description |
| --- | --- |
| **Client**  | Il **interroge** ou **écrit** des données : il demande l’accès à des services/valeurs. |
| **Serveur** | Il **fournit** les données (services/caractéristiques BLE). |

| Aspect | Centrale/Périphérique  | Client/Serveur |
| --- | --- | --- |
| Niveau | Connexion physique BLE | Accès aux données (GATT) |
| Centrale | Initie la connexion | En général client |
| Périphérique | Attend la connexion | En général serveur |
| Indépendants ? | ✅ Oui | ✅ Oui |

### Exemple pour SHT41 I2C sur Mbed
```c++
#include "mbed.h"

#define SHT41_ADDR (0x44 << 1) // Adresse I2C 7 bits décalée pour mbed

I2C i2c(I2C_SDA, I2C_SCL);
Serial pc(USBTX, USBRX, 115200); // Pour affichage série

char cmd_measure_high_prec[] = { 0xFD };
char data[6];

float convert_temperature(uint16_t raw) {
    return -45.0f + 175.0f * ((float)raw / 65535.0f);
}

float convert_humidity(uint16_t raw) {
    float rh = -6.0f + 125.0f * ((float)raw / 65535.0f);
    if (rh > 100.0f) rh = 100.0f;
    if (rh < 0.0f) rh = 0.0f;
    return rh;
}

int main() {
    while (true) {
        i2c.write(SHT41_ADDR, cmd_measure_high_prec, 1);
        wait_us(10000); // 10 ms
        // Je préfère ThisThread::sleep_for(10)

        if (i2c.read(SHT41_ADDR, data, 6) == 0) {
            uint16_t temp_raw = (data[0] << 8) | data[1];
            uint16_t hum_raw  = (data[3] << 8) | data[4];

            float temperature = convert_temperature(temp_raw);
            float humidity = convert_humidity(hum_raw);

            pc.printf("Temp: %.2f °C, RH: %.2f %%\r\n", temperature, humidity);
        } else {
            pc.printf("Erreur de lecture I2C.\r\n");
        }

        thread_sleep_for(2000); // 2 sec entre chaque lecture
    }
}
```

### 🛠️ Choix de configuration du capteur VEML6030

Dans ce code, le capteur VEML6030 est configuré en écrivant la valeur `0x4000` dans le registre de configuration `0x00` (`ALS_CONF`). Cette configuration active le capteur en mode **normal** (bit `ALS_SD = 0`), **sans interruption** (bit `ALS_INT_EN = 0`). Le gain est fixé à **x2** (`ALS_GAIN = 01`) pour une meilleure sensibilité en conditions de faible luminosité. Le **temps d’intégration** est réglé à **800 ms** (`ALS_IT = 0011`), ce qui permet une mesure plus précise et moins bruitée de la lumière ambiante. Ces paramètres donnent une résolution de **0.0042 lux/bit**, comme spécifié dans la documentation. Le registre `0x04` est ensuite lu pour obtenir la mesure brute (16 bits), qui est convertie en lux par un simple facteur multiplicatif.

```c++
#include "mbed.h"

#define VEML6030_ADDR (0x10 << 1) // ADDR connecté à GND -> adresse 0x20 write, 0x21 read

I2C i2c(I2C_SDA, I2C_SCL);
Serial pc(USBTX, USBRX, 115200); // Console série

char reg_als[] = { 0x04 };
char data[2];

float convert_lux(uint16_t raw) {
    // Gain x2, IT = 800 ms => 0.0042 lux/bit
    return raw * 0.0042f;
}

void init_veml6030() {
    // Configuration : Gain x2 (01), IT = 800 ms (0011), no interrupt, ALS ON
    // b0000 1000 1100 0000 => 0x08C0
    char config[] = { 0x00, 0xC0, 0x08 }; // Registre 0x00, LSB puis MSB
    i2c.write(VEML6030_ADDR, config, 3);
}

int main() {
    pc.printf("Initialisation VEML6030...\r\n");
    init_veml6030();

    while (true) {
        i2c.write(VEML6030_ADDR, reg_als, 1); // Demande de lecture registre 0x04
        if (i2c.read(VEML6030_ADDR, data, 2) == 0) {
            uint16_t als_raw = (data[1] << 8) | data[0]; // LSB first
            float lux = convert_lux(als_raw);

            pc.printf("Lumière ambiante: %u (%.3f lux)\r\n", als_raw, lux);
        } else {
            pc.printf("Erreur de lecture I2C\r\n");
        }

        thread_sleep_for(1000); // Attendre 1s avant nouvelle lecture
    }
}

```

| Bit(s) | Champ | Valeur binaire | Signification |
| --- | --- | --- | --- |
| 15:13  | Réservé | `000` | (doit être 0) |
| 12:11  | `ALS_GAIN` | `01` | Gain x2 |
| 10 | Réservé | `0` | - |
| 9:6 | `ALS_IT` | `0011` | Temps d'intégration = 800 ms |
| 5:4 | `ALS_PERS` | `00` | Persistance = 1 lecture |
| 3:2 | Réservé | `00` | - |
| 1 | `ALS_INT_EN` | `0` | Pas d’interruption |
| 0 | `ALS_SD` | `0` | Capteur activé (non éteint)  |

```
bit:  15-13 | 12-11 | 10 | 9-6   | 5-4 | 3-2 | 1 | 0
val:    000 |   01  | 0  | 0011  | 00  | 00  | 0 | 0    -> 0x08C0
```

Dans la datasheet, page 9 (tableau “REFRESH TIME, IDD, AND RESOLUTION RELATION”), on peut lire :

| ALS\_GAIN | PSM Mode | ALS\_IT (ms) | Résolution (lx/bit) |
| --- | --- | --- | --- |
| x2 | 1 | 800 | **0.0042** |

### Déclarations des entrées-sorties

```c++
// ATTENTION, ASSIGNIATION À DÉFINIR !!

// ADC
AnalogIn probe0(PC2);
AnalogIn probe1(PC1);
AnalogIn batMeas(PC0);

// Button
InterruptIn button(BUTTON1);

// Leds
DigitalOut led0(LED0);
DigitalOut led1(LED1);

// Float
DigitalIn  floatIn(FLOAT_IN);
DigitalOut floatOut(FLOAT_OUT);

// MOSFET Relays
DigitalOut relay0(RELAYS0);
DigitalOut relay1(RELAYS1);

// Load Switch Enable
DigitalOut pr0En(PC10);
DigitalOut pr1En(PC11);
DigitalOut lumiEn(PB0);
DigitalOut tempEn(PB1);

DigitalOut batMeasEn(PC4);
```

## Mercredi 04.06

## Jeudi 05.06

## Vendredi 06.06

Un thread par évènement asynchrone (ex réceptioniste - administration)

Une event_queue possède déjà un thread

Il faut lister les différents travaux, s'il sont indépendants on peut créer deux thread

On a copié le dossier hors du drive.

Setup software : bash -> powershell

Arguments :
- BLE et 802.15.4 2.4 GHz -> même portée
- grand public donc petite portée ok
- BLE mieux documenté MBed 

## Samedi 07.06

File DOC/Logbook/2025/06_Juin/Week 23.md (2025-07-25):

# Semaine 23, du lundi 09.06 au dimanche 15.06 2025

## Résumé de la semaine

## Lundi 09.06

## Mardi 10.06

```c
I2C i2c(I2C3_SDA, I2C3_SCL);

#define STTS22H_WRITE_ADDR 0x70  
#define STTS22H_READ_ADDR  0x71

#define WHO_AM_I_REG       0x01
#define CTRL_REG1          0x04
#define TEMP_OUT_L         0x06
#define TEMP_OUT_H         0x07

void write_register(uint8_t reg, uint8_t value) {
    char data[2] = { (char)reg, (char)value };
    i2c.write(STTS22H_WRITE_ADDR, data, 2);
}

uint8_t read_register(uint8_t reg) {
    char data = reg;
    char result;
    i2c.write(STTS22H_WRITE_ADDR, &data, 1);
    i2c.read(STTS22H_READ_ADDR, &result, 1);
    return result;
}

float read_temperature() {
    char reg = TEMP_OUT_L;
    char data[2];
    i2c.write(STTS22H_WRITE_ADDR, &reg, 1);
    i2c.read(STTS22H_READ_ADDR, data, 2);
    int16_t raw_temp = (int16_t)((data[1] << 8) | (uint8_t)data[0]); // Little endian
    return raw_temp / 100.0f; // Selon configuration par défaut
}

int main() {
    printf("STTS22H Init\n");

    uint8_t who_am_i = read_register(WHO_AM_I_REG);
    printf("WHO_AM_I: 0x%X\n", who_am_i);

    write_register(CTRL_REG1, 0x0C); // Incrément auto et FREERUN

    while (true) {
        float temp = read_temperature();
        printf("Temperature: %.2f C\n", temp);
        ThisThread::sleep_for(1s);
    }
}

```

## Mercredi 11.06

## Jeudi 12.06

Remarque importante de Yann : Interuption -> **EventFlag**.
Dans le callback on set le flag et dans le while(1) `wait_for`

Il faut mettre une pull-up pour le bouton : `btn0.mode(PullUp);`

Actuellement, la communication I2C ne fonctionne pas (pas d'ACK pour les *read* et *write*)

## Vendredi 13.06

La communication I2C fonctionne. Le circuit ne comporte pas de pull-up, le composant non plus. Il faut donc activer 
une pull-up interne au MCU. Cela se passe dans `PeripheralPins.c`, les `GPIO_NOPULL` du I2C3 sont remplacés par `GPIO_PULLUP`. 

Le GAP dans BLE gère la découverte, l'établissement de la connexion, la gestion des rôles des appareils, et d'autres interactions de base dans la communication sans fil entre les appareils BLE.

## Samedi 14.06

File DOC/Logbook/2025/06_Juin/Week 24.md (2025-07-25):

# Semaine 24, du lundi 16.06 au dimanche 22.06 2025

## Résumé de la semaine

## Lundi 16.06

Le GAP gère toujours la connexion, même avec GATT. On a une adresse *MAC* en BLE.

L’**advertising** (publicité) en BLE est le mécanisme par lequel un périphérique annonce sa présence aux autres (généralement les clients).

Le contenu des paquets publiés est le suivant (+- standardisé):
- Nom du périphérique
- Adresse MAC
- UUID de services
- Données optionnelles (apparence, fabricant, etc.)

La **pile BLE** est l'ensemble des couches logicielles qui implémentent le protocole Bluetooth Low Energy, elle comprend notamment GAP, GATT, ATT, HCI, etc.

Le payload est la donnée transmise dans les paquets advertising BLE. C’est ce que voit un client BLE quand il scanne.

`on_init_complete` : Callback appelé une fois l'initialisation de la pile BLE terminée pour configurer l’environnement.

La classe **GattServerProcess** est un utilitaire mbed qui encapsule :
- L'initialisation du BLE (ble.init()),
- La configuration du GAP (nom, mode publicité, etc.),
- Le démarrage de la publicité BLE.

Code *Update Characteristics* :
```
main()
 └── crée GattServerProcess + ClockService
         └── GattServerProcess.on_init() → ClockService::start()
                 ├── Enregistre le service (_clock_service) auprès du GattServer
                 ├── Enregistre ClockService comme EventHandler BLE
                 └── Lance l'incrément périodique via EventQueue

```

Une caractéristique GATT peut avoir plusieurs propriétés combinées par OU binaire (|), comme : `READ | WRITE | NOTIFY | INDICATE`.
Le serveur annonce ce qu’il autorise via les propriétés et le client agit en conséquence.

**Handlers (gestionnaires d’événements)** : spécifiques au serveur GATT. Elles sont appelées automatiquement par la pile BLE quand un événement lié à une caractéristique se produit.

| Handler | Événement déclencheur côté client | Rôle côté serveur |
| --- | --- | --- |
| `onDataSent(...)` | Une notification ou indication vient d’être envoyée | Confirmation que le serveur a bien transmis |
| `onDataWritten(...)` | Le client écrit dans une caractéristique | Permet de réagir (log, mise à jour, validation) |
| `onDataRead(...)` | Le client lit une caractéristique | Permet de tracer ou de vérifier un accès |
| `onUpdatesEnabled(...)` | Le client s’abonne à `NOTIFY` ou `INDICATE` | Permet de savoir quel client écoute quoi |
| `onUpdatesDisabled(...)` | Le client se désabonne | Idem, pour le suivi |
| `onConfirmationReceived(...)` | Le client a acquitté une `INDICATE` | Confirmation de réception (obligatoire pour `INDICATE`) |
| `authorize_client_write(...)` | Le client veut écrire une valeur | Permet d’accepter ou refuser **dynamiquement** l’écriture (validation, sécurité, etc.) |

`authorize_client_write(...)` n’est pas une surcharge de `GattServer::EventHandler`, mais un callback d'autorisation attaché manuellement ici :
`_hour_char.setWriteAuthorizationCallback(this, &ClockService::authorize_client_write);`

Il permet de bloquer ou valider une écriture avant qu’elle soit appliquée (ici, valeurs numériques valides uniquement).

Les handlers permettent au serveur :
- de réagir à toutes les opérations du client,
- de tracer, valider, ou refuser des actions,
- d'implémenter des règles métier (ex : borne horaire).

Une **surcharge** (override), c’est quand une classe dérivée remplace une méthode virtuelle de la classe de base, pour personnaliser son comportement.

Avec MBed OS, c'est un client à la fois.

**GattServer** : outil pour gérer les interactions GATT réelles (services, caracs, événements).
**GattServerProcess** : classe mbed facilitatrice qui initialise BLE + GAP + GATT, et appelle ton code quand prêt.

`BLE &ble = BLE::Instance();` : Instance centrale pour accéder à la pile BLE.

On ne peut pas passer `event_flags` par référence à une ISR (`btn1_irq`, `btn2_irq`) classique, pour une raison fondamentale : les fonctions ISR sont des callbacks sans argument imposées par *Mbed*.

**BlueNRG_2** est réservé aux cibles sans BLE intégré, le code suivant devrait être ajoutée dans le mbed_app.json si un pépin apparait. Le README.md des exemples BLE mentionne cet ajout pour d'autres cartes mais ça peut être une piste.
```json
"DISCO_WB5MMG": {
    "target.features_add": ["BLE"],
    "target.extra_labels_add": ["CORDIO"]
}
```

Lien pour les utils BLE de MBed OS : https://github.com/ARMmbed/mbed-os-ble-utils/tree/master.
`pretty_printer.h`, `ble_process.h` et `gatt_server_process.h` en ont été téléchargés pour utiliser la classe *GattServerProcess*

`I2C &bus` est une référence vers un objet I2C passé au constructeur. L’initialiseur : `_i2c(bus)` assigne directement cette référence au membre `_i2c` lors de la construction.

| Élément | Rôle |
| --- | --- |
| `set(...)` | Écrit manuellement une valeur dans le GATT BLE. |
| `call_every(..., update_temperature)` | Exécute périodiquement une fonction qui lit + appelle `set(...)`. |

```css
[INFO][BLCO]: WSF Cordio tracing enabled
[INFO][BLE ]: Allocated 2250 bytes for Cordio
[INFO][BLE ]: BLE features enabled: EXTENDED_ADVERTISING GATT_CLIENT GATT_SERVER PERIODIC_ADVERTISING PHY_MANAGEMENT PRIVACY SECURE_CONNECTIONS SECURITY SIGNING WHITELIST
[INFO][BLE ]: BLE roles enabled: PERIPHERAL CENTRAL
[INFO][BLE ]: Initialising Cordio host stack
[DBG ][BLE ]: HCI handler id: 0
[DBG ][BLE ]: DM handler id: 1
[DBG ][BLE ]: L2C slave handler id: 2
[DBG ][BLE ]: ATT handler id: 3
[DBG ][BLE ]: SMP handler id: 4
[DBG ][BLE ]: stack handler id: 5
[INFO][BLPR]: Initialize privacy PAL
Ble process started.
[INFO][BLE ]: Initialising BLE instance
[INFO][BLHC]: CordioHCIDriver initializing
[INFO][BLWB]: init_debug ENABLED
[DBG ][BLWB]: syscmd_status_not, status:1
[DBG ][BLWB]: syscmd_status_not, status:0
[DBG ][BLWB]: syscmd_status_not, status:1
[INFO][BLWB]: WIRELESS COPROCESSOR FW VERSION ID = 1.13.2
[INFO][BLWB]: WIRELESS COPROCESSOR FW STACK TYPE = 1 (ROM size 0xca000)
[DBG ][BLE ]: Cordio HCI reset started
[DBG ][BLWB]: mbox_write type:1, len:3
[INFO][BLWB]: TX>> BLE CMD
[DBG ][BLWB]:   Type 1
[DBG ][BLWB]:    Cmd c03
[DBG ][BLWB]:    Len 0
[DBG ][BLE ]: Reset sequence command complete: 0c03
[DBG ][BLWB]: Command Complete Event Command
[DBG ][BLWB]:   HCI_EVT_HDR_LEN=2
[DBG ][BLWB]:   opcode = 000c03
[INFO][BLWB]: WB Reset Received
[INFO][BLWB]: Found Unique Device Number: 6f00a3
[DBG ][BLWB]: mbox_write type:1, len:11
[INFO][BLWB]: TX>> BLE CMD
[DBG ][BLWB]:   Type 1
[DBG ][BLWB]:    Cmd fc0c
[DBG ][BLWB]:    Len 8
[INFO][BLWB]: Setting Bdaddr: a3:00:6f:27:e1:80
[DBG ][BLE ]: Reset sequence command complete: fc0c
[DBG ][BLWB]: Command Complete Event Command
[DBG ][BLWB]:   HCI_EVT_HDR_LEN=2
[DBG ][BLWB]:   opcode = 00fc0c
[DBG ][BLWB]: Bluetooth Device address set
[DBG ][BLWB]: mbox_write type:1, len:5
[INFO][BLWB]: TX>> BLE CMD
[DBG ][BLWB]:   Type 1
[DBG ][BLWB]:    Cmd fc0f
[DBG ][BLWB]:    Len 2
[DBG ][BLE ]: Reset sequence command complete: fc0f
[DBG ][BLWB]: Command Complete Event Command
[DBG ][BLWB]:   HCI_EVT_HDR_LEN=2
[DBG ][BLWB]:   opcode = 00fc0f
[DBG ][BLWB]: Tx Power Level set
[DBG ][BLWB]: mbox_write type:1, len:11
[INFO][BLWB]: TX>> BLE CMD
[DBG ][BLWB]:   Type 1
[DBG ][BLWB]:    Cmd c01
[DBG ][BLWB]:    Len 8
[DBG ][BLE ]: Reset sequence command complete: 0c01
[DBG ][BLWB]: Command Complete Event Command
[DBG ][BLWB]:   HCI_EVT_HDR_LEN=2
[DBG ][BLWB]:   opcode = 000c01
[DBG ][BLWB]: mbox_write type:1, len:11
[INFO][BLWB]: TX>> BLE CMD
[DBG ][BLWB]:   Type 1
[DBG ][BLWB]:    Cmd 2001
[DBG ][BLWB]:    Len 8
[DBG ][BLE ]: Reset sequence command complete: 2001
[DBG ][BLWB]: Command Complete Event Command
[DBG ][BLWB]:   HCI_EVT_HDR_LEN=2
[DBG ][BLWB]:   opcode = 002001
[DBG ][BLWB]: mbox_write type:1, len:3
[INFO][BLWB]: TX>> BLE CMD
[DBG ][BLWB]:   Type 1
[DBG ][BLWB]:    Cmd 1009
[DBG ][BLWB]:    Len 0
[DBG ][BLE ]: Reset sequence command complete: 1009
[DBG ][BLWB]: Command Complete Event Command
[DBG ][BLWB]:   HCI_EVT_HDR_LEN=2
[DBG ][BLWB]:   opcode = 001009
[DBG ][BLWB]: mbox_write type:1, len:3
[INFO][BLWB]: TX>> BLE CMD
[DBG ][BLWB]:   Type 1
[DBG ][BLWB]:    Cmd 2002
[DBG ][BLWB]:    Len 0
[INFO][BLWB]: Command Status event, status:1, opcode=0x2002
```

Il va surement falloir passer en mode debug pour voir où on bloque.

## Mardi 17.06

Le mode debug n'aide pas.

```css
[INFO][BLWB]: Command Status event, status:1, opcode=0x2002
```
indique une erreur **HCI_LE_READ_BUFFER_SIZE** selon l'AN https://www.st.com/resource/en/application_note/an5270-stm32wb-bluetooth-low-energy-wireless-interface-stmicroelectronics.pdf

Le **HCI** (Host Controller Interface) est une interface de communication entre le contrôleur Bluetooth (souvent un module ou une puce Bluetooth) et le hôte (généralement un microcontrôleur ou un processeur principal qui gère la pile Bluetooth et les applications associées).

**Analyse des logs**:
- HCI_RESET -> ok
- ACI_HAL_WRITE_CONFIG_DATA -> ok
- ACI_HAL_SET_TX_POWER_LEVEL -> ok
- HCI_SET_EVENT_MASK -> ok
- HCI_LE_SET_EVENT_MASK -> ok
- HCI_READ_BD_ADDR -> ok
- HCI_LE_READ_BUFFER_SIZE -> **PAS OK**

https://wiki.st.com/stm32mcu/wiki/Connectivity:STM32WB_BLE_Wireless_Stack

Le Wireless Coprocessor FW est le “cerveau radio” du STM32WB, c'est le microprogramme (“firmware”) qui s’exécute sur le cœur Cortex-M0+ (“CPU2”) des microcontrôleurs STM32WB.

Le fichier `stm32wb5x_BLE_Stack_full_fw.bin` est un firmware radio BLE “tout-en-un” à flasher sur CPU2 pour activer toutes les fonctions Bluetooth LE.

https://github.com/STMicroelectronics/STM32CubeWB/blob/master/Projects/STM32WB_Copro_Wireless_Binaries/STM32WB5x/Release_Notes.html 

https://forums.mbed.com/t/mbed-os-ble-stopped-working-on-stm32wb55-after-update-fus-and-ble-stack-to-version-1-14-1/18387

https://community.st.com/t5/stm32-mcus-wireless/stm32wb55rg-hci-driver-communication-problems-after-ble-stack/td-p/107056

Le FUS (Firmware Upgrade Service) est un composant logiciel intégré dans les microcontrôleurs STM32WB (notamment sur la puce CPU2). Son rôle principal est de gérer les opérations de mise à jour et de sécurité du firmware sans fil (Bluetooth, Thread, Zigbee, etc.) sur les STM32WB.

https://htmlpreview.github.io/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

**ACI** (Application Communication Interface) : Interface entre l'application (logique de haut niveau) et le firmware BLE, simplifiant l'accès aux fonctionnalités BLE.

**HCI** (Host Controller Interface) : Interface entre le host (processeur principal) et le contrôleur Bluetooth, permettant de gérer la communication sans fil.

**HAL** (Hardware Abstraction Layer) : Couche d'abstraction matérielle qui permet au stack Bluetooth de fonctionner indépendamment du matériel sous-jacent.

| Abréviation | Signification complète  | Description |
| --- | --- | --- |
| **LO** | **Link Layer Only** | Implémentation avec uniquement la couche liaison (LL), sans pile complète. |
| **PO** | **Peripheral Only** | Implémentation BLE agissant uniquement comme périphérique (slave). |
| **BO** | **Beacon Only** | Implémentation très minimale, souvent utilisée pour les balises (beacons). |
| **BF** | **Basic Functionality** | Configuration de base avec un ensemble limité de fonctionnalités BLE. |
| **LB** | **Link Layer Basic** | Version basique de la couche liaison, encore plus restreinte que LO. |

MEMORY
{ 
  FLASH (rx) : ORIGIN = MBED_APP_START, LENGTH = MBED_APP_SIZE
  RAM (rwx)   : ORIGIN = MBED_RAM_START + VECTORS_SIZE, LENGTH = 0x30000 - VECTORS_SIZE
  RAM2a (rw)  : ORIGIN = 0x20030000, LENGTH = 10K
  RAM2b (rw)  : ORIGIN = 0x20038000, LENGTH = 20K
}

    .ble_stby_mem (NOLOAD) :
    {
      *(MAPPING_TABLE);
      *(MB_MEM1);
    } >RAM2a

https://github.com/ARMmbed/mbed-os/commit/ca28a86d1b2120b0c2816b99d40b36fe1f968fb0

https://wiki.st.com/stm32mcu/wiki/Connectivity:STM32WB_BLE_Wireless_Stack

Fonctionne avec une adresse MAC aléatoire. `stm32wb5x_BLE_HCILayer_fw.bin` v1.12.0 pour le FUS.

https://htmlpreview.github.io/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

Chercher la version du firmware dans les commits GitHub.

Comme on a pas la version *extended*, pas de modif du .ld à faire. CubeIDE c'est GCC. On aurait pu demandé à GPT de modifier le .ld pour nous.

## Mercredi 18.06

**Différents binaires** : https://github.com/STMicroelectronics/STM32CubeWB/tree/master/Projects/STM32WB_Copro_Wireless_Binaries/STM32WB5x

**Explications FW M0** : https://github.com/ARMmbed/mbed-os/tree/master/targets/TARGET_STM/TARGET_STM32WB

Ca ne fonctionnait plus mais ça a été résolu en reflashant le FW en suivant rigoureusement les instructions du README.md des targets 

```
* connect the board with ST-LINK
* In the left column, go to "Firmware Upgrade Services"
* "Start FUS"
* "Read FUS infos" => version v1.2.0 is expected
* Firmware Upgrade / "Browse" : select the chosen FW (see above)
* Firmware Upgrade / Start address : depends on the chosen FW (see above)
* Firmware Upgrade / "Firmware Upgrade"
* In the left column, go to "Option bytes"
* User Configuration => "Read"
* User Configuration / enable nSWBOOT0 => "Apply"
```
J'ai également rajouté, conformément à ce README.md, la ligne suivante dans le `mbed_app.json`.

```json
"DISCO_WB5MMG": {
    "target.mbed_rom_size": "0xE1000"
}
```

Ce qui nous a fait passer de :

```css
[INFO][BLWB]: WIRELESS COPROCESSOR FW VERSION ID = 1.12.0
[INFO][BLWB]: WIRELESS COPROCESSOR FW STACK TYPE = 0 (ROM size 0xca000)
```
à :

```css
[INFO][BLWB]: WIRELESS COPROCESSOR FW VERSION ID = 1.12.0
[INFO][BLWB]: WIRELESS COPROCESSOR FW STACK TYPE = 0 (ROM size 0xe1000)
```
En essayant la version *update* ce message apprait après une longue série de logs.

```
++ MbedOS Error Info ++
Error Status: 0x8001012F Code: 303 Module: 1
Error Message: Error - writing to a file in an ISR or critical section

Location: 0x802492B
Error Value: 0x1
Current Thread: rtx_idle Id: 0x20000DC4 Entry: 0x8003A79 StackSize: 0x380 StackMem: 0x20000E08 SP: 0x2002FDAC 
For more info, visit: https://mbed.com/s/error?error=0x8001012F&tgt=DISCO_WB5MMG
-- MbedOS Error Info --
```

Le problème semble venir des classes *process* car ça fonctionne pour l'exemple *GAP* ou l'*Advertising*.

Le test *HeartRate* fonctionne ! C'est l'exemple `BLE_GattServer_AddService`, renommé `main_add_serv.cpp`.
Le repo est le suivant : https://github.com/ARMmbed/mbed-os-example-ble/tree/mbed-os-6.7.0/BLE_GattServer_AddService
Attention, le **service HeartRate** est déjà existant et comporte des méthodes, il faudrait peut-être s'en inspirer pour 
mettre à jour les données sans lever d'erreurs. https://github.com/ARMmbed/ble/blob/master/ble/services/HeartRateService.h

Il existe déjà un *ReadOnlyGattCharacteristic* dans `GattCharacteristic.h`. Attention il y a de légères diff entre le GitHub et le `.h` !

Maintenant, il faut adapter ce code pour transmettre une température.

## Jeudi 19.06

La norme Bluetooth standardise le format de nombreuses caractéristiques pour permettre à chaque appareil de les lire. Exemple pour le Heart Rate : https://www.bluetooth.com/specifications/specs/heart-rate-service-1-0/.

Exemple de service/caractéristiques 

```c
// Déclaration des UUID pour les services et caractéristiques
static const ble::UUID temperature_service_uuid(0x181A); // UUID pour le service de température (selon Bluetooth SIG)
static const ble::UUID humidity_service_uuid(0x181A);    // UUID pour le service d'humidité
static const ble::UUID luminosity_service_uuid(0x1234);  // Exemple de UUID pour le service de luminosité

static const ble::UUID temperature_char_uuid(0x2A6E); // UUID pour la caractéristique de température
static const ble::UUID humidity_char_uuid(0x2A6F);    // UUID pour la caractéristique d'humidité
static const ble::UUID luminosity_char_uuid(0x1235);   // Exemple de UUID pour la caractéristique de luminosité

// Définition des services et des caractéristiques
ble::GattService temperature_service(temperature_service_uuid);
ble::GattService humidity_service(humidity_service_uuid);
ble::GattService luminosity_service(luminosity_service_uuid);

// Ajouter les caractéristiques aux services respectifs
temperature_service.addCharacteristic(temperature_char_uuid, ble::GattCharacteristic::PROPERTY_READ);
humidity_service.addCharacteristic(humidity_char_uuid, ble::GattCharacteristic::PROPERTY_READ);
luminosity_service.addCharacteristic(luminosity_char_uuid, ble::GattCharacteristic::PROPERTY_READ);

// Enregistrement des services sur le périphérique BLE
_ble.gattServer().addService(temperature_service);
_ble.gattServer().addService(humidity_service);
_ble.gattServer().addService(luminosity_service);

```

Excellent, on parvient à publier les valeurs de température !! C'est avec le `main_temp_service.cpp`, dérivé de `main_add_serv.cpp`, et avec le service perso de `ble_temperature_service.h`. Les valeurs envoyées sont en Big Endian donc il faut les lire à l'envers. On reçoit le message *[INFO][BLGS]: Write attribute 13 - value=08:0c, local_only=false* chaque seconde, indépendamment de la présence d'un client.

À présent, je vais développer le code Python pour être capable de lire ces infos.

Ca fonctionne. Avec Bleak, l'UUID doit avoir ce format 128 bits : `0000xxxx-0000-1000-8000-00805f9b34fb` avec l'UUID 16 bits utilisés côté MCU qui remplace les *xxxx*. Ex : 0x181A -> 0000181a-0000-1000-8000-00805f9b34fb. Contrairement au format des données durant le transport, on récupère les valeurs en *Little Endian*, il faut donc cette extraction :

```python
def notification_handler(sender, data):
    value = struct.unpack("<h", data)[0]  # int16, little-endian
    temperature = value / 100.0
    print(f"Température: {temperature} °C")
```

Fonctionnement d'une event_queue avec exécution infinie :

```c
int main() {
    // Planifier une tâche répétitive toutes les 1000 ms
    _event_queue.call_every(1000ms, update_sensor_value);

    // Planifier une tâche immédiate
    _event_queue.call(immediate_task);

    // Exécuter la boucle d'événements
    _event_queue.dispatch_forever();
}
```

Pour stopper la pile BLE :

```c
void stop()
    {
        if (_ble.hasInitialized()) {
            _ble.shutdown();
            printf("Ble process stopped.");
        }
    }
```

Un **handle** dans le contexte du Bluetooth Low Energy (BLE) et de l'API Mbed OS fait référence à un identifiant ou un pointeur utilisé pour désigner un objet ou une ressource particulière au sein du stack BLE. Ici, il est associé à un processus de publicité particulier.

```c
// démarre le processus de publicité (ce n'est pas une boucle)
error = _ble.gap().startAdvertising(ble::LEGACY_ADVERTISING_HANDLE);

// suspend le processus
error = _ble.gap().stopAdvertising(ble::LEGACY_ADVERTISING_HANDLE);
```

L'**EventQueue** dans Mbed OS est une structure utilisée pour gérer l'exécution asynchrone de fonctions ou d'événements. Elle permet de programmer l'exécution différée de certaines tâches ou de répéter certaines actions à intervalles réguliers.

Le **Legacy Advertising** est le mode de publicité traditionnel dans BLE, basique mais plus ancien et limité que le **Extended Advertising**.

`ble::Gap::EventHandler` est une classe dans le stack Bluetooth Low Energy (BLE) de Mbed OS qui permet de gérer les événements associés à la **GAP** (Generic Access Profile) de Bluetooth.

La communication **PHY 2M** fait référence à l'utilisation d'une vitesse de transmission de données de 2 Mbps (Mégabits par seconde) en BLE, spécifiquement avec la PHY (Physical Layer) 2M introduite avec la spécification Bluetooth 5.0.

**Legacy Advertising vs Extended Advertising** :

| **Caractéristique** | **Legacy Advertising** | **Extended Advertising** |
| --- | --- | --- |
| **Introduit dans** | Bluetooth 4.0/4.2 | Bluetooth 5.0 |
| **Vitesse de transmission** | 1 Mbps (PHY 1M) | 1 Mbps (PHY 1M), 2 Mbps (PHY 2M), etc. |
| **Taille des paquets publicitaires** | 31 octets max | Jusqu'à 255 octets |
| **Canaux de publicité** | 3 canaux (37, 38, 39) | Jusqu'à 37 canaux |
| **Mode de publicité** | Simple, peu flexible | Flexible, configurable |
| **Compatibilité** | Large compatibilité avec tous les périphériques BLE | Nécessite Bluetooth 5.0 ou supérieur |
| **Idéal pour** | Applications simples avec peu de données | Applications complexes avec plus de données ou des besoins spécifiques |

Dans notre cas on peut rester en *Legacy*.

**EventQueue vs Thread** :

| **Caractéristique** | **`EventQueue`** | **`Thread`** |
| --- | --- | --- |
| **Nature** | Gestion d'événements asynchrones, exécution différée | Exécution concurrente de tâches (multitâche) |
| **Multitâche réel** | Non (utilise une seule boucle d'événements) | Oui (exécution de plusieurs threads en parallèle) |
| **Blocage** | Non-bloquant, gère les événements sans bloquer le programme principal | Peut être bloqué ou suspendu |
| **Utilisation** | Exécution d'événements ou de tâches à des moments précis ou périodiques | Tâches qui nécessitent un traitement parallèle, intensif ou de longue durée |
| **Simplicité** | Facile à utiliser pour des tâches légères et asynchrones | Plus complexe, nécessite la gestion de la synchronisation entre threads |
| **Coût en ressources** | Moins coûteux en termes de mémoire et de ressources | Plus coûteux en ressources, nécessite plus de mémoire pour chaque thread |

**`OK_main_temp_service.cpp`** contient le code fonctionne pour l'envoi de température en continu, maintenant je repars de ça pour créer un thread BLE et l'interrompre avec un bouton.

On arrive à lancer et couper la communication BLE avec le bouton. Maintenant le temps de `dispatch` doit être suffiamment long (2-3s), idéalement il faudrait pouvoir recevoir l'info que le client a lu les données pour faire le `event_queue.break_dispatch()` mais pour cela il faut modifier le callback `onDataRead` de `ble.gattServer()`, ce qui ne marche pas.

## Vendredi 20.06

Yann le GOAT a trouvé comment faire fonctionner le callback (il fallait un pointeur et non une référence comme argument). Cependant, cette technique n'est plus à jour et il est conseillé d'utiliser un `GattServer::EventHandler`.

Parfois la stack BLE se relance direct après l'avoir shutdown. Il faut vérifier comment vraiment bien la détruire et ajouter peut-être une variable `activateBLE` ou vérifier qu'on a pas eu de rebond avec le bouton pour ne pas reconstruire une instance par erreur.

Compléter la liste de UUID pour la publicité :

```c
UUID service_uuids[] = { _temperature_uuid, _ack_service.getUUID() }; // getUUID() doit retourner un UUID
_adv_data_builder.setLocalServiceList(mbed::make_Span(service_uuids, 2));
```

Il faut essayer de mettre en place ce `GattServer::EventHandler`, ça permettrait notamment d'être notifié lorsque le raspberry envoit une info (au lieu de lire en boucle comme un plouc).

Mettre au propre onDataWritten et les handlers.

## Samedi 21.06

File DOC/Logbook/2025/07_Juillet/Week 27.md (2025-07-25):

# Semaine 27, du lundi 07.07 au dimanche 13.07 2025

## Résumé de la semaine

## Lundi 07.07

Avancement sur le code *Rainette*. Utilisation d'un singleton pour RainetteIO.

Il faut continuer le code *Rainette* en créant les 2 modes de fonctionnement.

Attention résoudre le problème de réf croisées avec `GattServerEventHandler::onDataWritten` et `RainetteApp::handleDataWritten`.

## Mardi 08.07

Implémentation de timeout et autres. Division par des données sur client.

Logique à vérifier.

## Mercredi 09.07

Code `rainette` presque fini, il faut encore terminé un coup. Les cartes et les composants sont arrivés, une 1e carte a été montée.
Pour le moment par de problèmes au niveau de l'alimentation.

Le connecteur *tag-connect* ne matchait pas avec le *ST-Link* donc liaisons recomposées avec des fils.

## Jeudi 10.07

L'USB fonctionne aussi. Début des modifications du code *disco* pour reprendre la forme du code *rainette* propre.

Peut-être un problème d'accès aux membres privés pour `handleDataWritten`, à creuser.. EN effet on ne peut pas accéder aux membres.

Ok, en utilisant un `event_flags` on peut contrer ce problème. Il faut encore résoudre le problème du singleton.

Vérifier la cohérence du code `rainette`.

## Vendredi 11.07

Code rainette compilé, `PB_0` et `PB_1` ne sont pas présents dans le fichier `PinNames.h` donc à voir lors de l'adaptation sur la nouvelle target.

FW de la carte *Rainette* programmé correctement avec *CubeProgrammer*, du premier coup ! 🎉🎉

Créer les fichiers de configs avec le script Python : https://github.com/ARMmbed/mbed-os/tree/master/targets/TARGET_STM#board-specific-files-pinmap

```bash
damien@LAPTOP-L2M9U4N6:/mnt/c/Users/Damien/Dropbox/PC/Documents/Code Rainette/Rainette/mbed-os$ python3 targets/TARGET_STM/tools/STM32_gen_PeripheralPins.py -m "STM32WB5MMGHx.xml"

Script version 1.20.5

Checking STM32_open_pin_data repo...
        Already up to date.

STM32_open_pin_data DB version STM32CubeMX-DB.6.0.90

 * Output directory: /mnt/c/Users/Damien/Dropbox/PC/Documents/Code Rainette/Rainette/mbed-os/TARGET_CUSTOM/TARGET_STM/TARGET_STM32WB/TARGET_STM32WB5MxG/TARGET_STM32WB5MMGH
 * Generating PeripheralPins.c and PinNames.h with 'STM32_open_pin_data/mcu/STM32WB5MMGHx.xml'
 * GPIO file: STM32_open_pin_data/mcu/IP/GPIO-STM32WB5Mx_gpio_v1_0_Modes.xml
 * I/O pins found: 73 connected: 1
```

Dans `PinNames.h`, on modifie les lignes suivantes pour indiquer les lignes RX et TX de la console, reliées ensuite au PC via l'USART.

```c
    // STDIO for console print
#ifdef MBED_CONF_TARGET_STDIO_UART_TX
    CONSOLE_TX = MBED_CONF_TARGET_STDIO_UART_TX,
#else
    CONSOLE_TX = PB_6,
#endif
#ifdef MBED_CONF_TARGET_STDIO_UART_RX
    CONSOLE_RX = MBED_CONF_TARGET_STDIO_UART_RX,
#else
    CONSOLE_RX = PB_7,
#endif
```

On arrive pas à flasher le programme avec OpenOCD mais on y arrive avec CubeProgrammer, en chargeant `Rainette.bin`.

Pour décompiler le code, on utilise la commande 

`arm-none-eabi-objdump -d Rainette_application.elf --start-address 0x801F800 --stop-address 0x801F8FF`

car l'erreur est la suivante et on on vise la gamme mémoire autour.

++ MbedOS Error Info ++
Error Status: 0x80FF0100 Code: 256 Module: 255
Error Message: Fatal Run-time error
Location: 0x801F84F
Error Value: 0x0
Current Thread: AppThread Id: 0x200047C0 Entry: 0x8024719 StackSize: 0x1000 StackMem: 0x20008020 SP: 0x20008E4C 
For more info, visit: https://mbed.com/s/error?error=0x80FF0100&tgt=RAINETTE
-- MbedOS Error Info --
ERROR booting WB controler

Il semblerait qu'il s'agisse d'un problème d'ordonnanceur (hypothèse seulement).

Symptômes à décrire à GPT (enchainement de breackpoint juste avant la lecture du sémaphore, mais pas le seul problème..).

Reset -> connect -> lâcher reset
1. FW FUS
2. Flasher avec CubeProgrammer (hypothèse)

## Samedi 12.07

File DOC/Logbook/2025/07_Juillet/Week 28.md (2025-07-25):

# Semaine 28, du lundi 14.07 au dimanche 20.07 2025

## Résumé de la semaine

## Lundi 14.07

Ca refonctionne pour la carte `disco` en appuyant sur le bouton *Start Wireless Stack* dans le FUS de STMCubeProgrammer.
On peut par la suite reflasher depuis *OpenOCD*.

Il faudrait recréer une autre config pour custom target pour la disco afin d'y déposer les codes pour ne pas devoir couper-coller les nouveaux codes à chaque fois.

La programmation fonctionne en respectant les étapes suivantes :
1. Connect
2. Upgrade firmware
3. Read FUS info et Start Wireless Stack
4. Flasher le binaire avec CubeProgrammer

Il faut encore débugger le capteur de lumi et l'ADC batterie (facteur correctif ?). On peut essayer d'ajouter le pull-up dans le MCU pour voir.

## Mardi 15.07

Pour la mesure de batterie, les valeurs des résistances sont bonnes, la Zener est dans le bon sens. 

**Mesure *battMeas***
1V -> 0V
1.5V -> 0.712V
2V -> 1.33V
2.5V -> 1.5V
3V -> 1.62V
3.5 -> 1.7V
4V -> 1.77V
4.5V -> 1.83V

**Mesure sortie de transistor**
1V -> 0V
1.5V -> 0.9V
2V -> 1.87V
2.5V -> 2.36V
3V -> 2.84V
3.5 -> 3.3V
4V -> 3.82V
4.5V -> 4.32V

Ces mesures ont permis la création du fichier `sim_fact_corr.ipynb` qui permet de passer des valeurs mesurées aux valeurs attendues en appliquant un facteur correctif.

Coefficients du polynôme (x = a*y² + b*y + c):
a = 5.187502, b = -11.389900, c = 7.911509 

Sondes OK
GPIO OK
Lumi toujours nul malgré les pull ups ajoutées
ADC ajusté donc OK

La connexion GAP est drôlement plus merdique avec la carte Rainette, il faut inspecter les différences pour trouver la cause.

Il faut regarder le flotteur encore et les connexions GAP sont encore bien trop aléatoires..

## Mercredi 16.07

Sur la 2e carte montée sans diode Zener pour la mesure de la batterie, le pont diviseur fonctionne parfaitement, c'est donc la diode qui introduit ce problème.

Bon vraiment je pige pas le problème avec lumi..

Dans l'état, on a une conso moyenne de 7mA, même au repos, ce qui est largement trop. Faut trouver comment activer ce foutu mode *DeepSleep*. Il y a un pic à 680mA lors de la mesure !!

`Deep sleep allowed: No`

Bon faut contrôler ce ***** de port série afin de checker le mode deepsleep et vérifier pourquoi on a ce pic de courant de con. 

## Jeudi 17.07

## Vendredi 18.07

**Yann** : 
- Le comportement peut être attendu, il faudrait diminuer les valeurs de résistances du pont diviseur pour que l'impédance de la diode soit vraiment supérieure au pont diviseur.
- Il faudrait gicler le condo 10uF du capteur de luminosité car il est surement responsable du maxi pic et c'est inutile car il est activé pendant un court instant. Il faudrait également vérifier les signaux SDA et SCL à l'oscillo.
- Bastien si connait un peu en mode *deepsleep* et **il faut utiliser le mode RELEASE**.

Si on mesure avec le PPK2 sur la place du jumper, on obtient aussi 7mA donc le problème ne vient pas de ce qu'il y a avant.

L'ajout de `"MBED_SLEEP_TRACING_ENABLED"` dans mbed_app.json permet de voir ce qui lock le deepsleep

Ex :
`deepsleep locked by: [lp_ticker.c x 1] [i2c_api.c x 1] [SysTimer.cpp x 1]`
`deepsleep unlocked`

Le fait d'instancier un bus i2c peut bloquer le mode deepsleep, il faudrait uniquement le créer lorsque l'on s'apprête à faire des mesures.

```c++
I2C* myi2c = new I2C(SDA,SCL);

myi2c->read();
myi2c->write();

delete myi2c;
```

C'était en effet la bonne chose à faire pour débloquer le *deepsleep*, maintenant l'i2c est présent uniquement au moment de la mesure.

Il faut tester la conso avec un code minimal. On peut aussi créer une fonction dans le main qu'on appelle en `extern`
dans `wb_sleep.c` pour toggle une led lorsqu'on rentre dans le mode deepsleep.

Dans `targets`->`TARGET_STM`->`TARGET_STM32WB`, le dossier `STMCube_FW` contient la **HAL ST**, elle n'est pas modifiable. Les fichiers c/h sont les fichiers écrits par Mbed pour employer la HAL sur la target, on peut les 
modifier. Le fichier `wb_sleep.c` concerne le deepsleep, on doit voir quel mode est activé (StopMode,..).

C'est mieux, la haute consommation était due au câble relié au ST-Link, il faut le retirer et faire un *reset*.

| Mode HAL | Économie | Horloge système | RAM sauvegardée | Consommation typique |
|---|---|---|---|---|
|`PWR_EnterSleepMode()` | Faible | Oui | Oui | \~1 mA typiquement |
|`PWR_EnterStopMode()`  | Moyen | Non | Oui | \~0.3–1 mA |
|`PWR_EnterOffMode()` | Élevé (Standby) | Non | Non | \~1 µA typiquement |

**Constatations** :
- init : DeepSleep dispo -> conso 5mA
- 1e attente : DeepSleep dispo -> conso 5mA
- 2e attente : DeepSleep plus dispo

La stack BLE pourrait être responsable, peut-être faudrait-il regarder le coprocesseur M0.

Liste non-exaustive des périphériques qui bloquent le mode *deep sleep* : 
    [timer, ticker, timeout, SPI, I2C, CAN, PWM, Serial, USB]

* Par défaut (sans `MBED_TICKLESS`)
    - Le systicker (SysTick, fréquence 1 kHz en général) génère une interruption toutes les millisecondes.
    - Cela empêche l’entrée en deep sleep (Stop Mode), car le timer système réveille constamment le CPU.
    - Consommation énergétique relativement élevée, même en veille.

* Avec `MBED_TICKLESS`
    - Le RTOS désactive le systicker périodique.
    - À la place, il programme un wakeup unique avec un Low Power Timer pour le prochain événement planifié.
    - Cela permet d’entrer automatiquement en deep sleep (Stop Mode) dès que possible.
    - Réduit significativement la consommation énergétique si le système passe souvent en veille.

Selon GPT :

- Faire `delete` sur une instance BLE allouée dynamiquement ne garantit pas l'arrêt du coprocesseur M0+.
- Avec `stm32wb5x_BLE_HCILayer_fw.bin`, on gère la pile BLE en Mbed/Cordio côté *M4*, et le M0+ joue le rôle de
  contrôleur HCI BLE pur. Il n’interprète aucun appel SHCI car le firmware minimal HCI ne contient pas le support SHCI (System HCI).

**SHCI**: *System Host Controller Interface*. Protocole d’extension propriétaire de ST qui permet au M4 de :
- Commander des transitions d’alimentation du M0+.
- Initialiser/désinitialiser les stacks sans fil (BLE, Thread, Zigbee).
- Reconfigurer le firmware radio sans redémarrer.

| Terme | Signification | Rôle principal |
| --- | --- | --- |
| RCC | Reset and Clock Control | Gérer les horloges et resets |
| IPCC | Inter-Processor Comm. Controller | Comm M4 ↔ M0+ |
| HSEM | Hardware Semaphore | Mutex entre M4 et M0+ |
| `__HAL_RCC_*_CLK_DISABLE()` | Macro HAL | Coupe l’horloge d’un domaine |

Solutions pour éteindre le M0+ : 
1. Couper explicitement le domaine réseau en passant par les HAL STM32Cube du projet.
2. Changer de firmware pour bénéficier de SHCI en utilisant une version *full*.

## Samedi 19.07

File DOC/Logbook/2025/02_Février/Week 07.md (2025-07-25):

# Semaine 07, du lundi 17.02 au dimanche 23.02 2025

## Résumé de la semaine

## Lundi 17.02

## Mardi 18.02

## Mercredi 19.02

## Jeudi 20.02

## Vendredi 21.02

## Samedi 22.02

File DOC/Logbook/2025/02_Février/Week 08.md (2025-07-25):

# Semaine 08, du lundi 24.02 au dimanche 02.03 2025

## Résumé de la semaine

## Lundi 24.02

## Mardi 25.02

## Mercredi 26.02

## Jeudi 27.02

## Vendredi 28.02

## Samedi 01.03

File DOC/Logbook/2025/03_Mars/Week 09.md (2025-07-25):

# Semaine 09, du lundi 03.03 au dimanche 09.03 2025

## Résumé de la semaine

## Lundi 03.03

## Mardi 04.03

## Mercredi 05.03

## Jeudi 06.03

## Vendredi 07.03

## Samedi 08.03

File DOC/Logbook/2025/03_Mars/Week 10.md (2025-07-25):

# Semaine 10, du lundi 10.03 au dimanche 16.03 2025

## Résumé de la semaine

## Lundi 10.03

## Mardi 11.03

## Mercredi 12.03

## Jeudi 13.03

## Vendredi 14.03

## Samedi 15.03

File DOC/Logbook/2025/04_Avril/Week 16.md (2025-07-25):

# Semaine 16, du lundi 21.04 au dimanche 27.04 2025

## Résumé de la semaine

## Lundi 21.04

## Mardi 22.04

## Mercredi 23.04

## Jeudi 24.04

## Vendredi 25.04

## Samedi 26.04

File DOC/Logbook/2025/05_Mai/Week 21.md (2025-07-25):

# Semaine 21, du lundi 26.05 au dimanche 01.06 2025

## Résumé de la semaine

## Lundi 26.05

## Mardi 27.05

Pour la bibliographie, utiliser ce format :
```latex
@online{1,
	author={Ferme},
	title = {La Ferme Aquaponique du Pays de Gex {\textbar} Versonnex},
	url = {https://www.lafermeaquaponique.com},
	urldate = {2025-03-25},
    shorthand = {FermeAqua2025}
}
```
et citer avec \cite{1}. Ca va afficher "FermeAqua2025" (shorthand)

Modification de la règle sur les freins thermiques : Design -> Rules -> Plane -> Polygon Connect Style

Update d'un footprint modifié : Clique droit -> Component Actions -> Update Selected Components From PCB Lib

En l'absence du prof, je commence à m'intéresser au code.

*bluepy* ou *bleak* pour communiquer en BLE sur le rapsberry.

| Élément | `Timer` | `Ticker` |
| --- | --- | --- |
| Rôle | Mesurer un temps écoulé | Déclencher une fonction périodiquement |
| Style | Contrôle manuel (`start`, `stop`) | Interruptions automatiques |
| Wakeup | Ne réveille pas | Peut réveiller le MCU |
| DeepSleep | ❌ (classique) | ✅ avec `LowPowerTicker` |
| Exemple | Chronométrer une opération | Réveil périodique pour capteur |

GATT (Generic Attribute Profile) est un protocole BLE qui définit comment deux appareils échangent des données selon un modèle client-serveur, structuré en services et caractéristiques. Le GattClient initie les requêtes pour lire ou écrire des données, tandis que le GattServer expose ces données et y répond. 

Eurocircuits : importer le zip des gerber. OubJob donné par Yann. 
On a récupéré les règles 7D en faisant un projet 7D Empty. Nouvelles règles -> redéfinir les règles sur les planes et les polygones. Modifier légèrement les vias. 

C/C++ tools..
Task Runner
Copy File Name
Cortex Debug

Il faut encore installer Mercurial, Mbed CLI et les requirements (voir lien Teams)

## Mercredi 28.05

## Jeudi 29.05

## Vendredi 30.05

## Samedi 31.05

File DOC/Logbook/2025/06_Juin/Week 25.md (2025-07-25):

# Semaine 25, du lundi 23.06 au dimanche 29.06 2025

## Résumé de la semaine

## Lundi 23.06

Début du travail sur le *DeepSleep*.

Un *Ticker* c'est comme un *Timeout* mais qui se répète périodiquement.

Dans le json, j'ai ajouté la macro `"MBED_TICKLESS"` et mis à `false` le paramètre `platform.stdio-buffered-serial`. À présent, le DeepSleep est lancé lorsqu'on dort `ThisThread::sleep_for(1s);`. Le fait de *locker* ce mode empêche le MCU d'y rentrer, cela ne nous contraint pas à y rester. Le snippet suivant montre bien cet effet :

```c
printf("Deep sleep allowed: %i\r\n", sleep_manager_can_deep_sleep()); // 1
ThisThread::sleep_for(1000);

// Lock deep sleep
printf("Locking deep sleep\r\n");
sleep_manager_lock_deep_sleep();

printf("Deep sleep allowed: %i\r\n", sleep_manager_can_deep_sleep()); // 0
ThisThread::sleep_for(1000);
```

Dans notre cas, faire `ThisThread::sleep_for(10min);` peut parfaitement faire l'affaire, pas besoin d'un ticker car lors du sommeil on attend aucun événement.

On peut essayer `constexpr auto SLEEP_TIME = 10min;`

#### Découpage des fichiers

* main.cpp

* services.h - services.cpp

* ble.h - ble.cpp

* utils.h - utils.cpp

#### Services et caractéristiques

**General**
* BattDetect
* StartMeas
* EndOfComm
* PingPong

**Analog**
* Probe0
* Probe1
* Lumi
* Temp
* Humi
* Batt

**Digital**
* Float
* MosRel0
* MosRel1
* Gpio0
* Gpio1
* Gpio2
* Gpio3
* Gpio4
* Button

**Cas ReadOnly**
- Le client lit manuellement la température chaque seconde.
- Tu déclares la caractéristique avec seulement GattCharacteristic::BLE_GATT_CHAR_PROPERTIES_READ.

**Cas Read + Notify**
- Le client s’abonne aux notifications.
- Le serveur appelle ble.gattServer().notify(...) à chaque mise à jour de température.
- Le client reçoit les nouvelles valeurs en temps réel, sans polling.

Création des fichiers `rainette_services.cpp` et `rainette_services.h`, il faut encore corriger les incohérences de types (bool <-> uint8_t).

## Mardi 24.06

Rédaction du rapport.

## Mercredi 25.06

Rédaction du rapport et amélioration des classes de services en ajoutant notamment des setter.

| Terme | Nature | Rôle principal | Exemple typique |
| --- | --- | --- | --- |
| **handle**  | Identifiant | Référence indirecte à une ressource | `GattAttribute::Handle_t` |
| **handler** | Fonction | Réagit à un événement, traite une action | `onConnectionHandler()` |

Création de `rainette_event_handlers.cpp` et `rainette_event_handlers.h`. Maintenant on peut voir chaque caractéristique.

## Jeudi 26.06

## Vendredi 27.06

Attention faut pas stocker l'état des I/O dans la stack BLE car en cas de problème ou de shutdown pour perd tout.

Problème avec le ping-pong test !

Vérifier les erreurs pour la GUI.

## Samedi 28.06

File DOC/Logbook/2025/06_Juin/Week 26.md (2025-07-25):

# Semaine 26, du lundi 30.06 au dimanche 06.07 2025

## Résumé de la semaine

## Lundi 30.06

Pas de pull-up/down sur les ADC mais pour la carte Rainette ça devrait le faire grâce au diviseur résistif.

On a droit à des spécialités avec la communication BLE, le client se connecte mais pas de nouveaux logs sur le serveur.

Création des fichiers `Disco` pour développer une app faite pour la carte Disco dans le cas où on aurait un pépin avec Rainette
pour la démo.

Il faut demander à Yann comment faire pour les event_flags et pour les `sleep_for` asynchrones. Comment faire pour envoyer une dernière trame depuis le serveur avant de couper la communication ?

## Mardi 01.07

Discussion avec Yann : classe BLEManagment pour gérer le tout.

Raspberry Pi OS installé sur une carte SD. Problème de formatage reglé avec diskpart :

```
select disk X     (remplacer X par le numéro de la carte SD)
clean
create partition primary
format fs=fat32 quick
assign
exit
```
Le code GUI posait problème car plusieurs boucles tournaient en même temps (toléré sur Windows mais pas sur Linux).
La nouvelle version corrige cela est le code fonctionne bien sur le Raspberry.

Il faut une partie `Mise en service et tests` dans le rapport.

Problème avec `schedule_ble_events` : soit membre de la classe mais il faut une fonction libre, soit event_queue hors de portée. Peut être faut il redéclarer event_queue dehors.. À voir avec Yann.

## Mercredi 02.07

Visite YOTAVIS

## Jeudi 03.07

Discussion avec Yann : 

* Rapport :
    - Pas trop d'exemples inutiles
    - Schémas d'architecture
    - Expliquer les points compliqués avec du code
    - GitHub pour le code, pas en dur dans les annexes
    - Expliquer les points à améliorer (découpage pas incr)

* Code :
    - Pas mélanger BLE avec applicatif
    - *Singleton* pour `BLEManagement` (mais un poussé, je préfère déclarer `event_queue` dehors)
    - Instance de `I2C` dans le main, puis `extern` dans `utils.h` pour créer les *callbacks* à cet endroit

On a des problèmes avec les resets, il faut encore explorer mais la méthode crée `reset()` pose problème dès la première communication si elle est évoquée avant `run()`.

## Vendredi 04.07

## Samedi 05.07

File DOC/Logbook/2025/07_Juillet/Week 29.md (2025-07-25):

# Semaine 29, du lundi 21.07 au dimanche 27.07 2025

## Résumé de la semaine

## Lundi 21.07

Il fallait aussi activer le capteur de température lorsqu'on lit celui de luminosité. À présent on voit bien des trames I2C mais le résultat n'est toujours pas incroyable.

**I2C**
| Phase | Émetteur des données | Émetteur de l’ACK/NACK |
| --- | --- | ---|
| Adresse (R/W = 0 ou 1) | Maître | Esclave |
| Écriture (write) | Maître | Esclave |
| Lecture (read) | Esclave | Maître (NACK -> fin de comm) |

Tous les acknowledges sont ok côté capteur mais il envoit systématiquement 0000, ce qui n'est pas cohérent. Le premier bit du registre de config devrait être par défaut à 1, hors ce n'est pas le cas ici. Du coup, pas possible d'activer quoique ce soit, l'ID est aussi à 0000..

**M0+**
- Pas d’extinction/réactivation directe du M0+ depuis le code principal.
- Seulement des modes globaux (Standby/Shutdown) ou vérification d’état via les flags.

**Lib SparkFun capteur lumi** : https://github.com/sparkfun/SparkFun_Ambient_Light_Sensor_Arduino_Library/tree/master

## Mardi 22.07

La consommation sur pile est en fait bien inférieur, il fallait retirer le port série, qui consommait beaucoup.

Si on a encore un peu de temps en  fin de semaine, il faudrait faire ces tests **brute force** pour le capteur de température.

## Mercredi 23.07

## Jeudi 24.07

## Vendredi 25.07

## Samedi 26.07

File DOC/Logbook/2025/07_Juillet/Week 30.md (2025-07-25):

# Semaine 30, du lundi 28.07 au dimanche 03.08 2025

## Résumé de la semaine

## Lundi 28.07

## Mardi 29.07

## Mercredi 30.07

## Jeudi 31.07

## Vendredi 01.08

## Samedi 02.08

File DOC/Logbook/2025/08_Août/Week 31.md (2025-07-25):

# Semaine 31, du lundi 04.08 au dimanche 10.08 2025

## Résumé de la semaine

## Lundi 04.08

## Mardi 05.08

## Mercredi 06.08

## Jeudi 07.08

## Vendredi 08.08

## Samedi 09.08

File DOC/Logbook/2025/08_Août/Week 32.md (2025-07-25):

# Semaine 32, du lundi 11.08 au dimanche 17.08 2025

## Résumé de la semaine

## Lundi 11.08

## Mardi 12.08

## Mercredi 13.08

## Jeudi 14.08

## Vendredi 15.08

## Samedi 16.08

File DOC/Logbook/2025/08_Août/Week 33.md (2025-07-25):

# Semaine 33, du lundi 18.08 au dimanche 24.08 2025

## Résumé de la semaine

## Lundi 18.08

## Mardi 19.08

## Mercredi 20.08

## Jeudi 21.08

## Vendredi 22.08

## Samedi 23.08

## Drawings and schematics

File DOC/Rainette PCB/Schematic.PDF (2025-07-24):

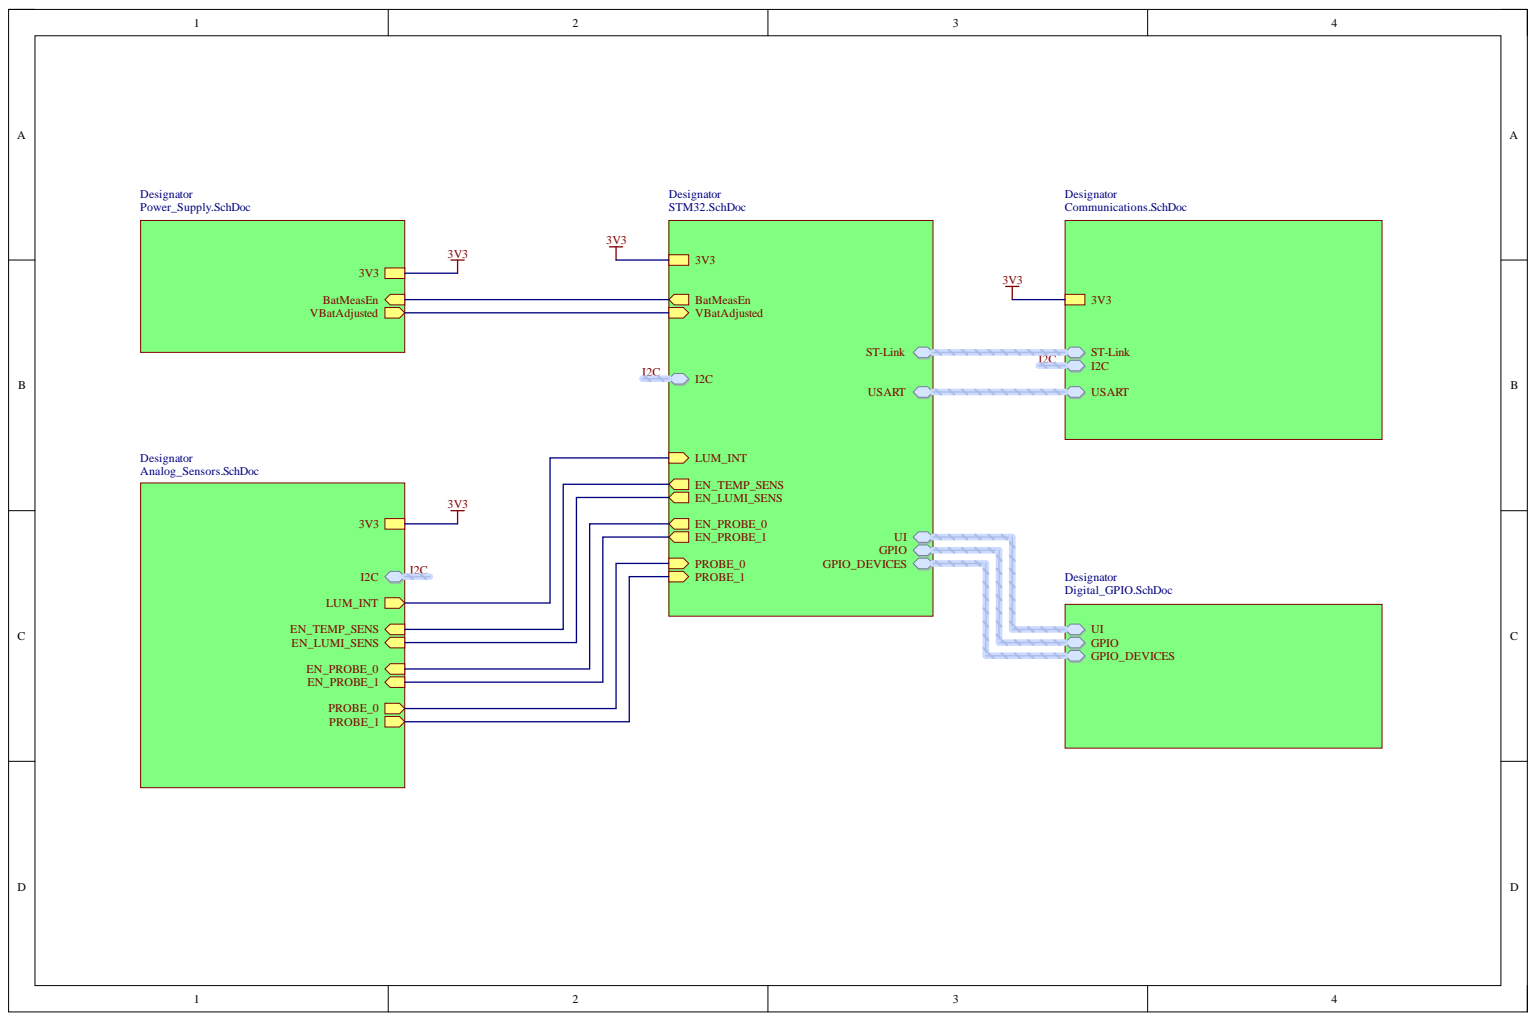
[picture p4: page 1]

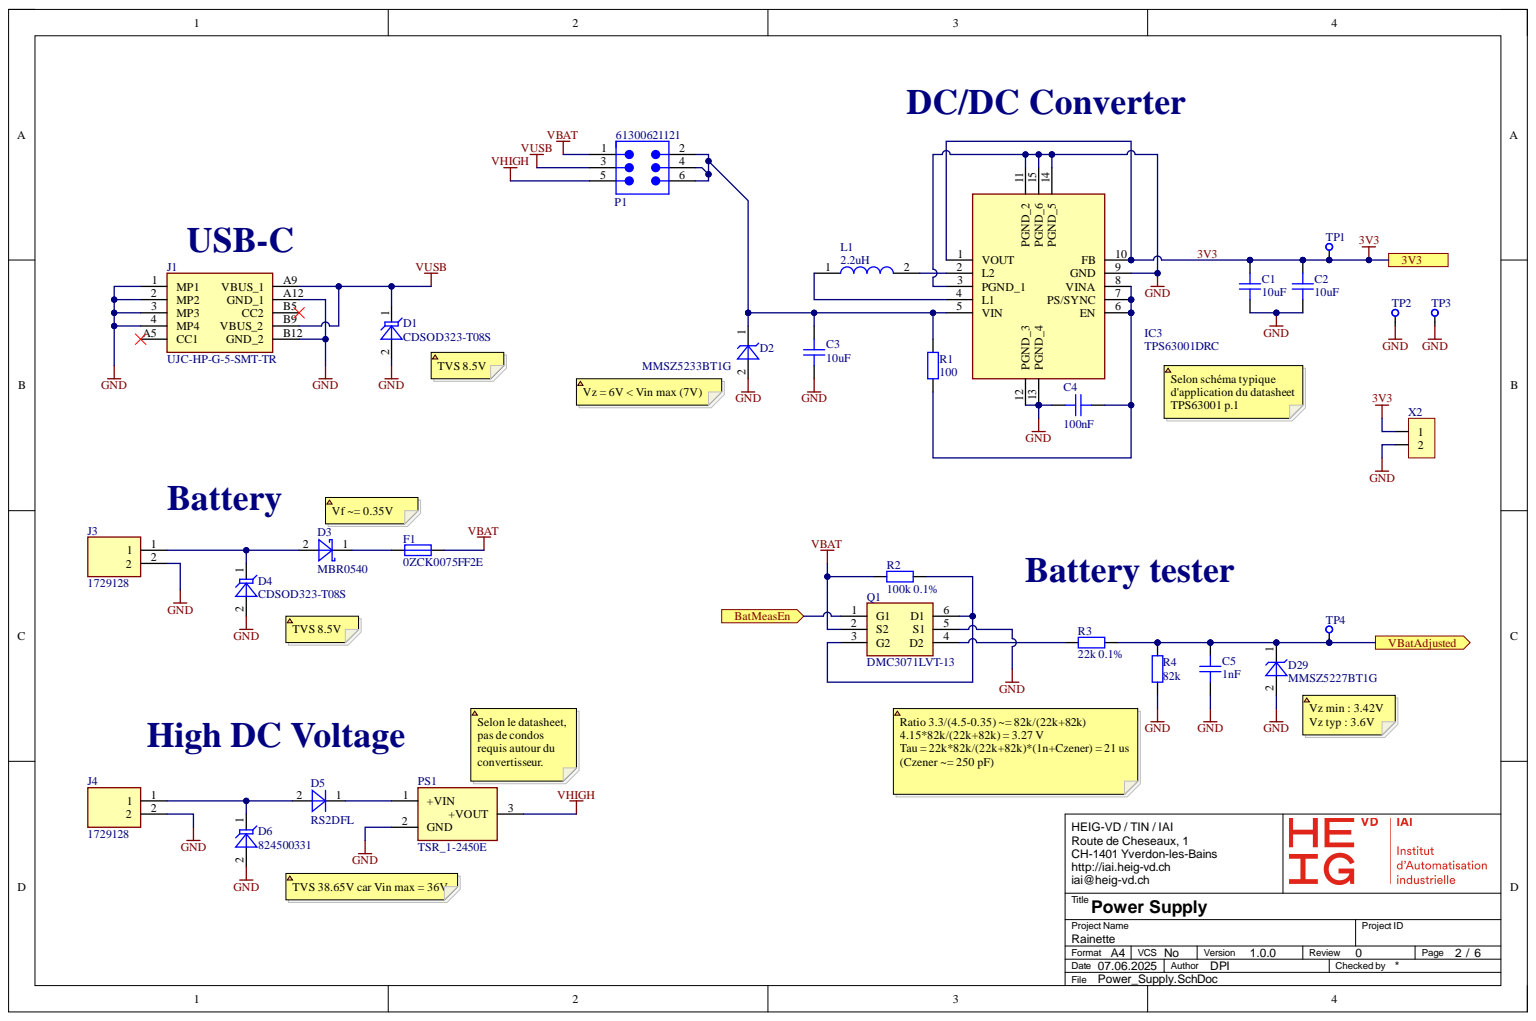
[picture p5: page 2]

UJC-HP-G-5-SMT-TR

HEIG-VD / TIN / IAI
Route de Cheseaux, 1
CH-1401 Yverdon-les-Bains
http://iai.heig-vd.ch
iai@heig-vd.ch
Power Supply

TVS 38.65V car Vin max = 36V

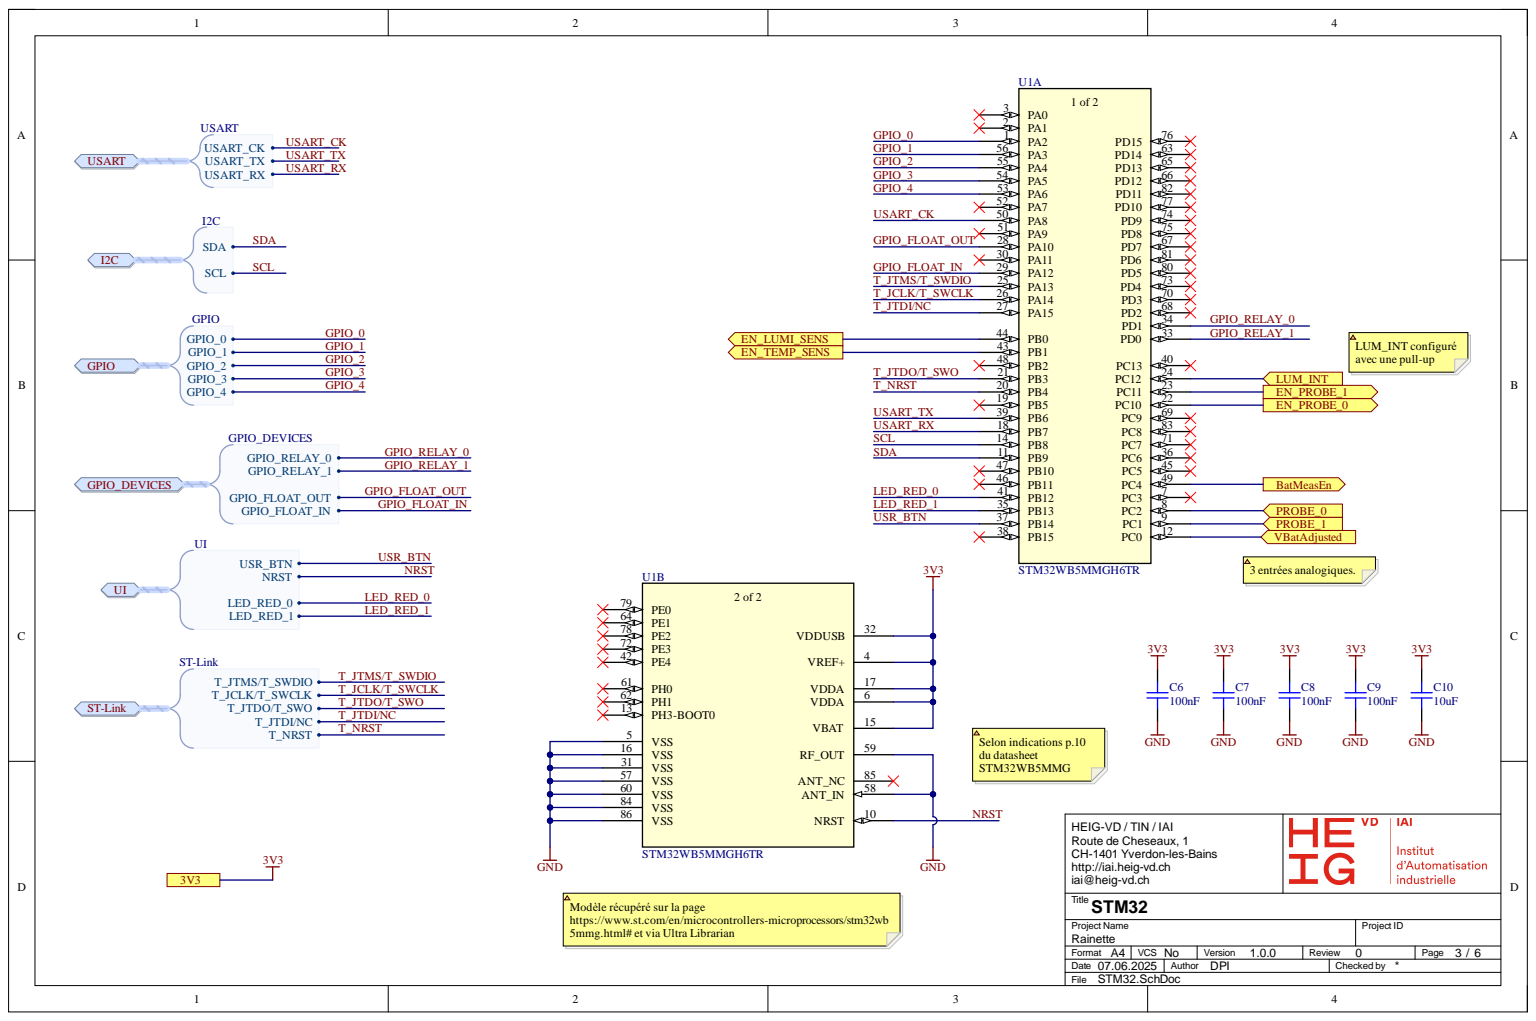
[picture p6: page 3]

LUM_INT configuré
avec une pull-up

HEIG-VD / TIN / IAI
Route de Cheseaux, 1
CH-1401 Yverdon-les-Bains
http://iai.heig-vd.ch
iai@heig-vd.ch
STM32

Modèle récupéré sur la page
https://www.st.com/en/microcontrollers-microprocessors/stm32wb
5mmg.html# et via Ultra Librarian

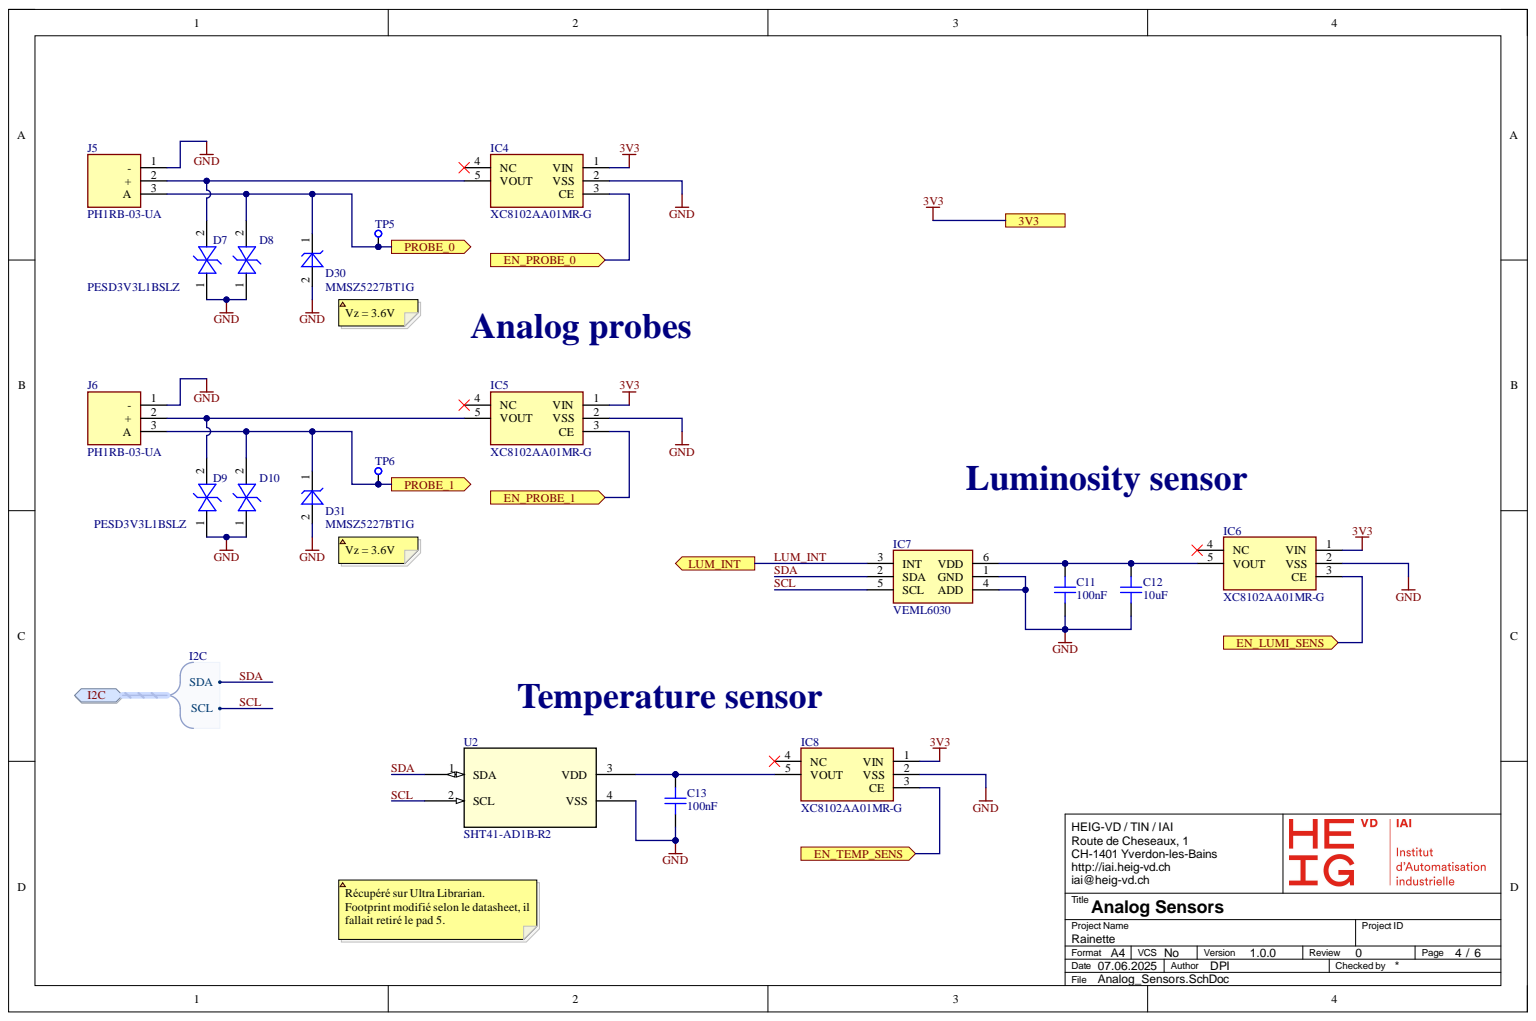
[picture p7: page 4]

HEIG-VD / TIN / IAI
Route de Cheseaux, 1
CH-1401 Yverdon-les-Bains
http://iai.heig-vd.ch
iai@heig-vd.ch
Analog Sensors

Récupéré sur Ultra Librarian.
Footprint modifié selon le datasheet, il
fallait retiré le pad 5.

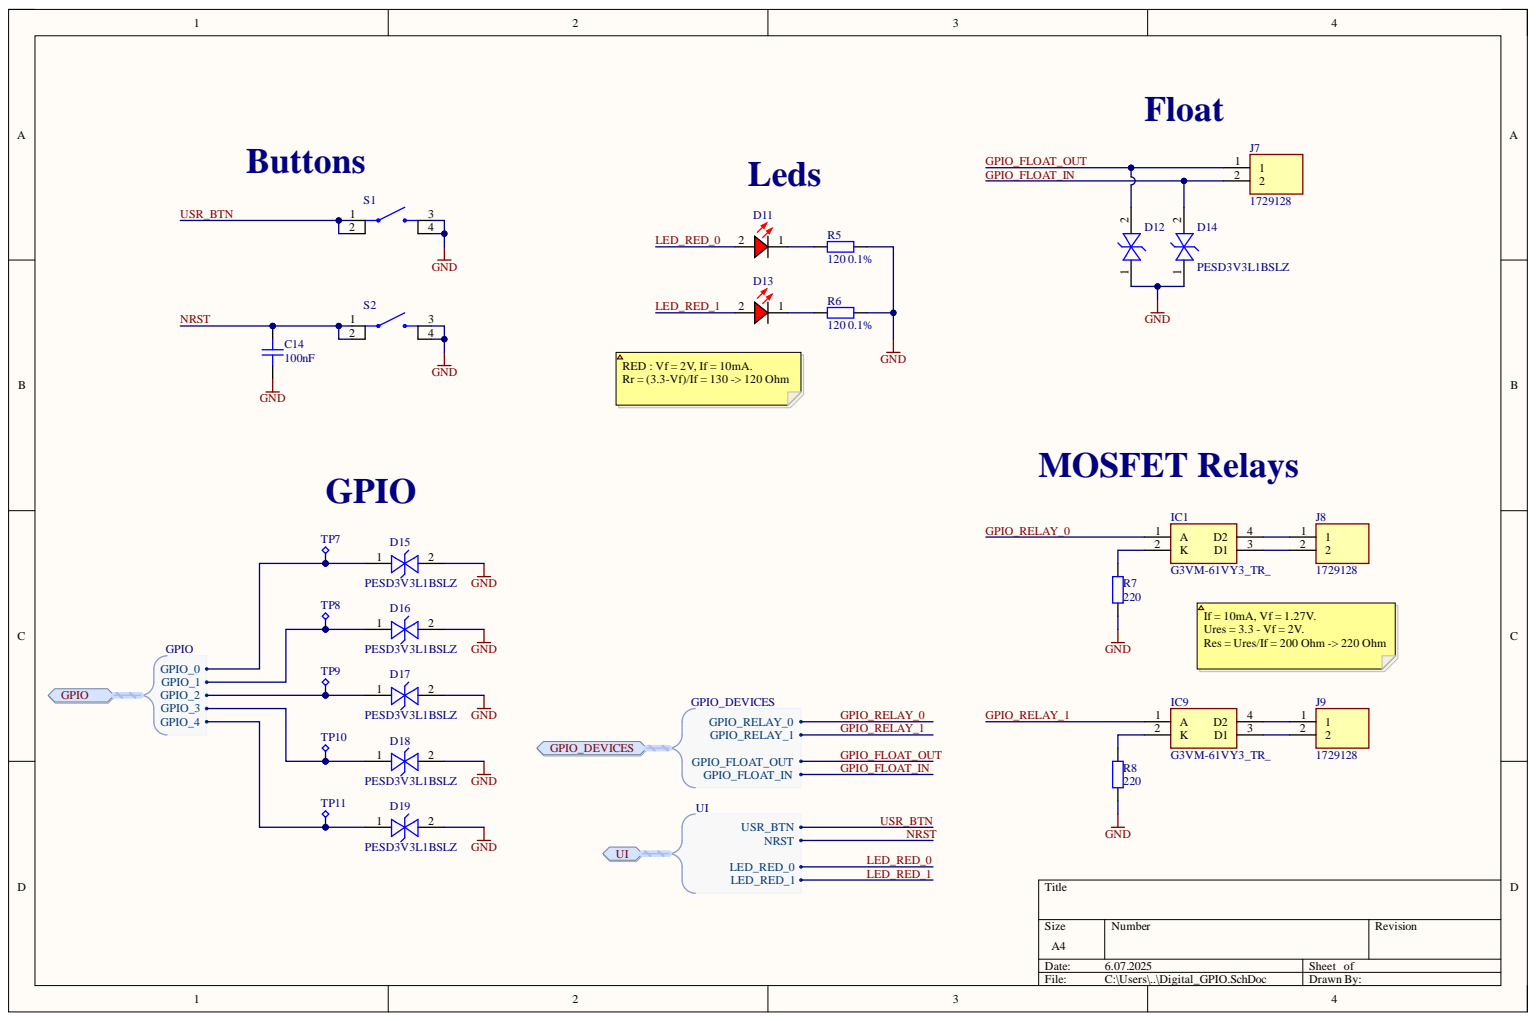
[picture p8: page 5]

RED : Vf = 2V, If = 10mA.
Rr = (3.3-Vf)/If = 130 -> 120 Ohm

Ures = 3.3 - Vf = 2V.
Res = Ures/If = 200 Ohm -> 220 Ohm

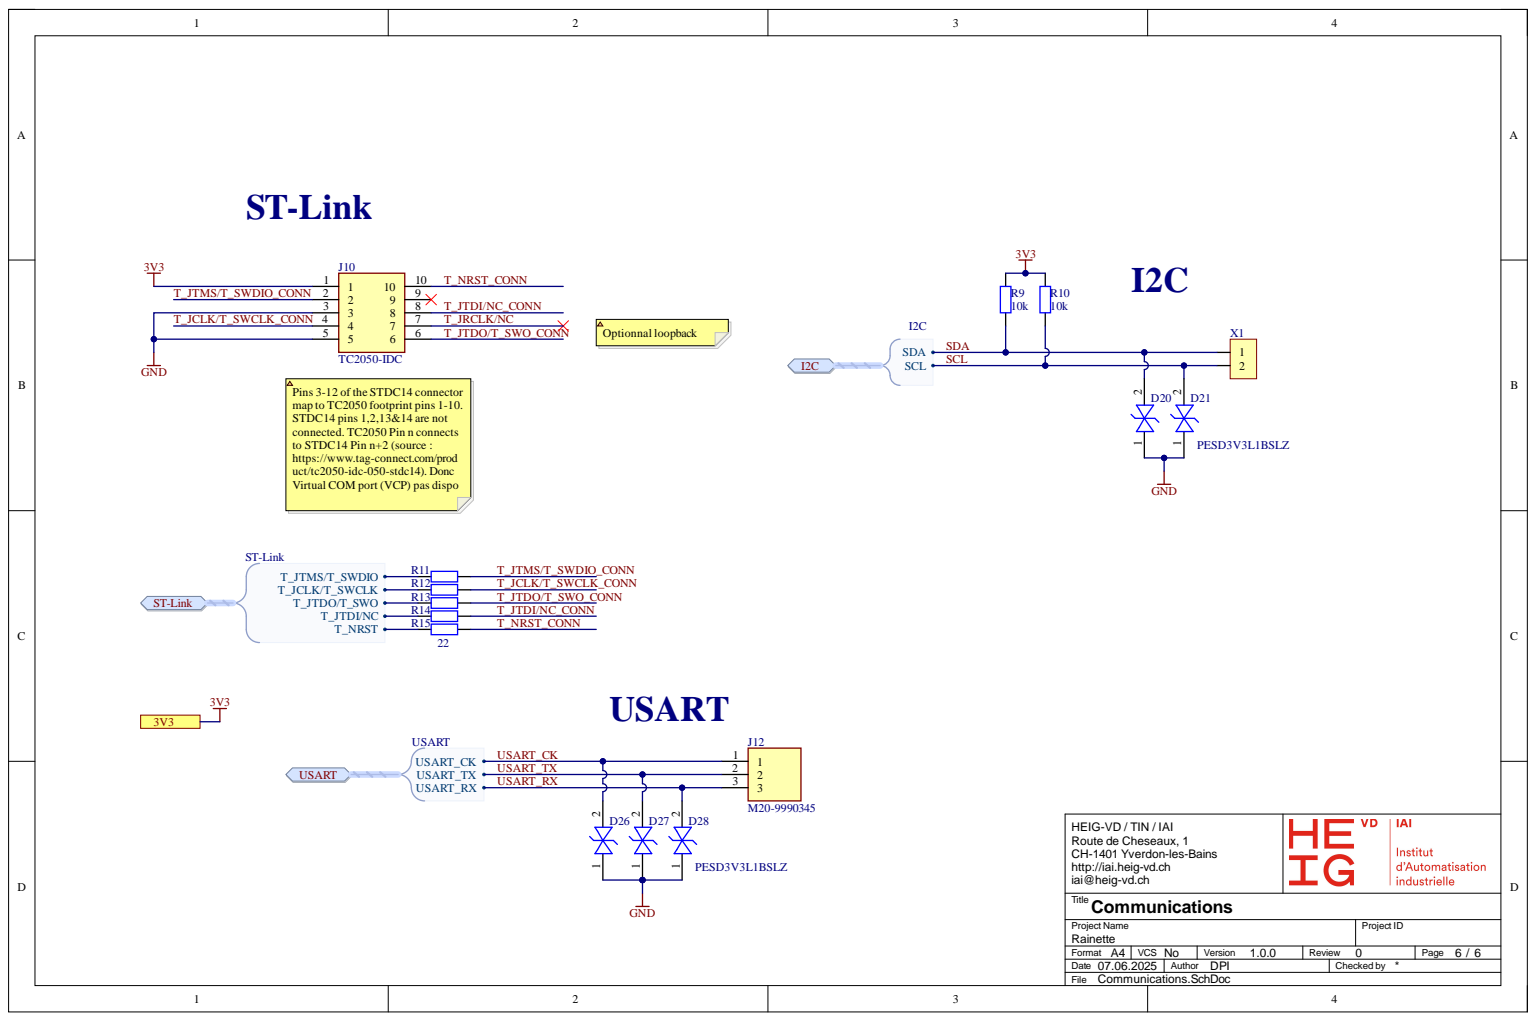
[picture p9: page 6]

Pins 3-12 of the STDC14 connector
map to TC2050 footprint pins 1-10.
STDC14 pins 1,2,13&14 are not
connected. TC2050 Pin n connects
to STDC14 Pin n+2 (source :
https://www.tag-connect.com/prod
uct/tc2050-idc-050-stdc14). Donc
Virtual COM port (VCP) pas dispo

HEIG-VD / TIN / IAI
Route de Cheseaux, 1
CH-1401 Yverdon-les-Bains
http://iai.heig-vd.ch
iai@heig-vd.ch
Communications

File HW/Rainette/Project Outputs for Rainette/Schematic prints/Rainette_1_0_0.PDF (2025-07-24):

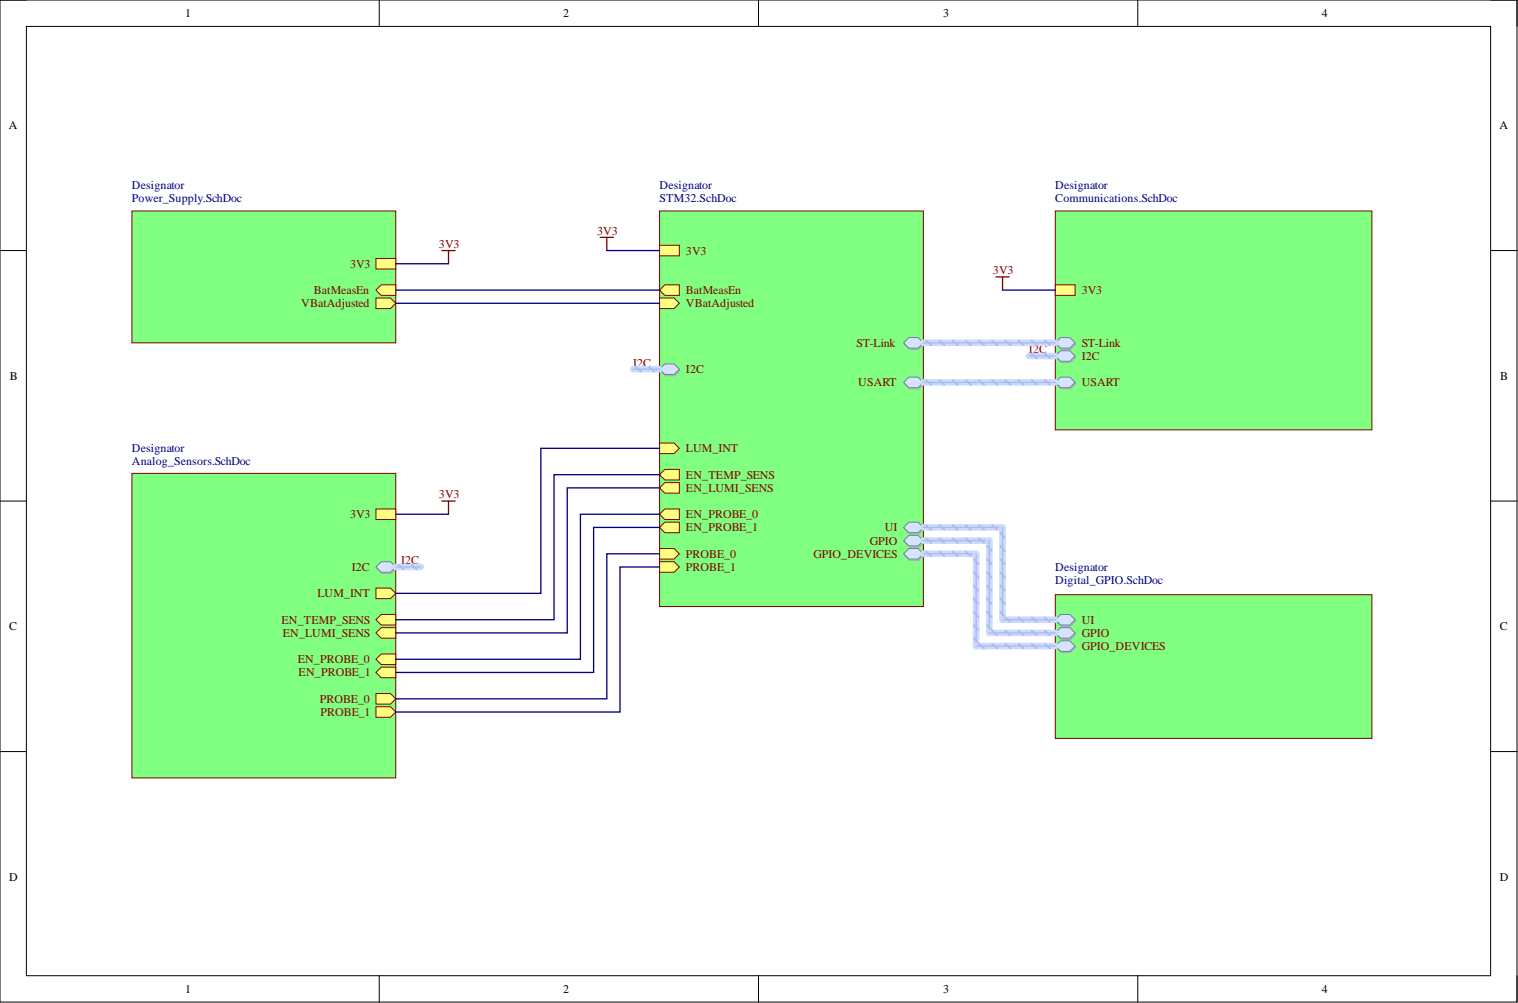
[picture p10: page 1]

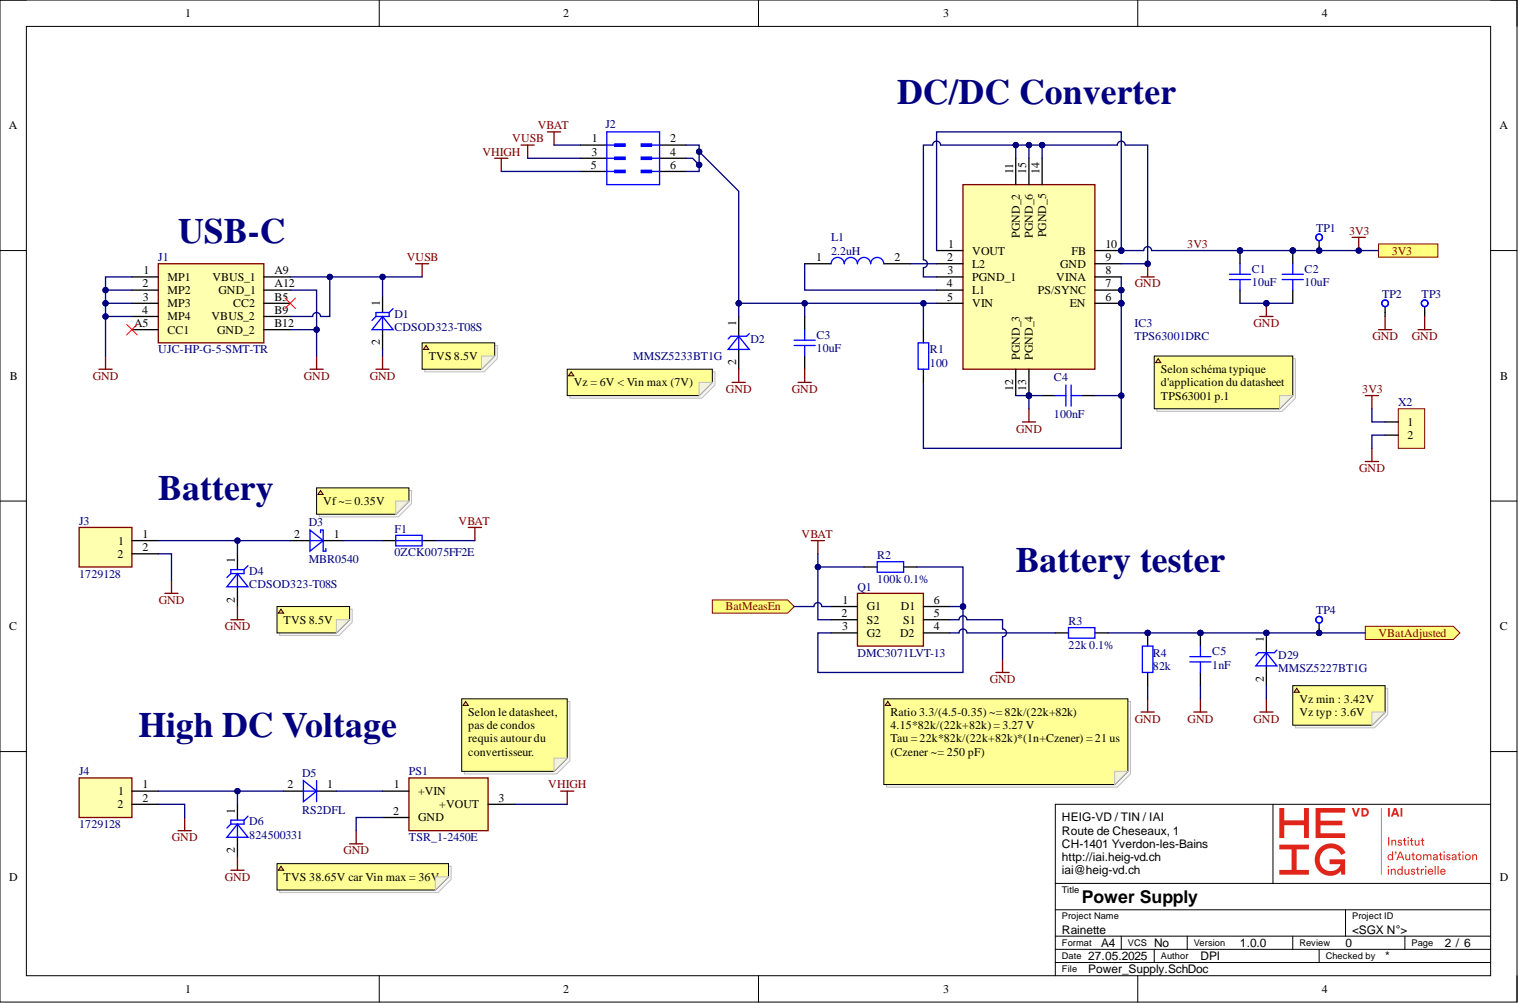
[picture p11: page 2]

UJC-HP-G-5-SMT-TR

HEIG-VD / TIN / IAI
Route de Cheseaux, 1
CH-1401 Yverdon-les-Bains
http://iai.heig-vd.ch
iai@heig-vd.ch
Power Supply

TVS 38.65V car Vin max = 36V

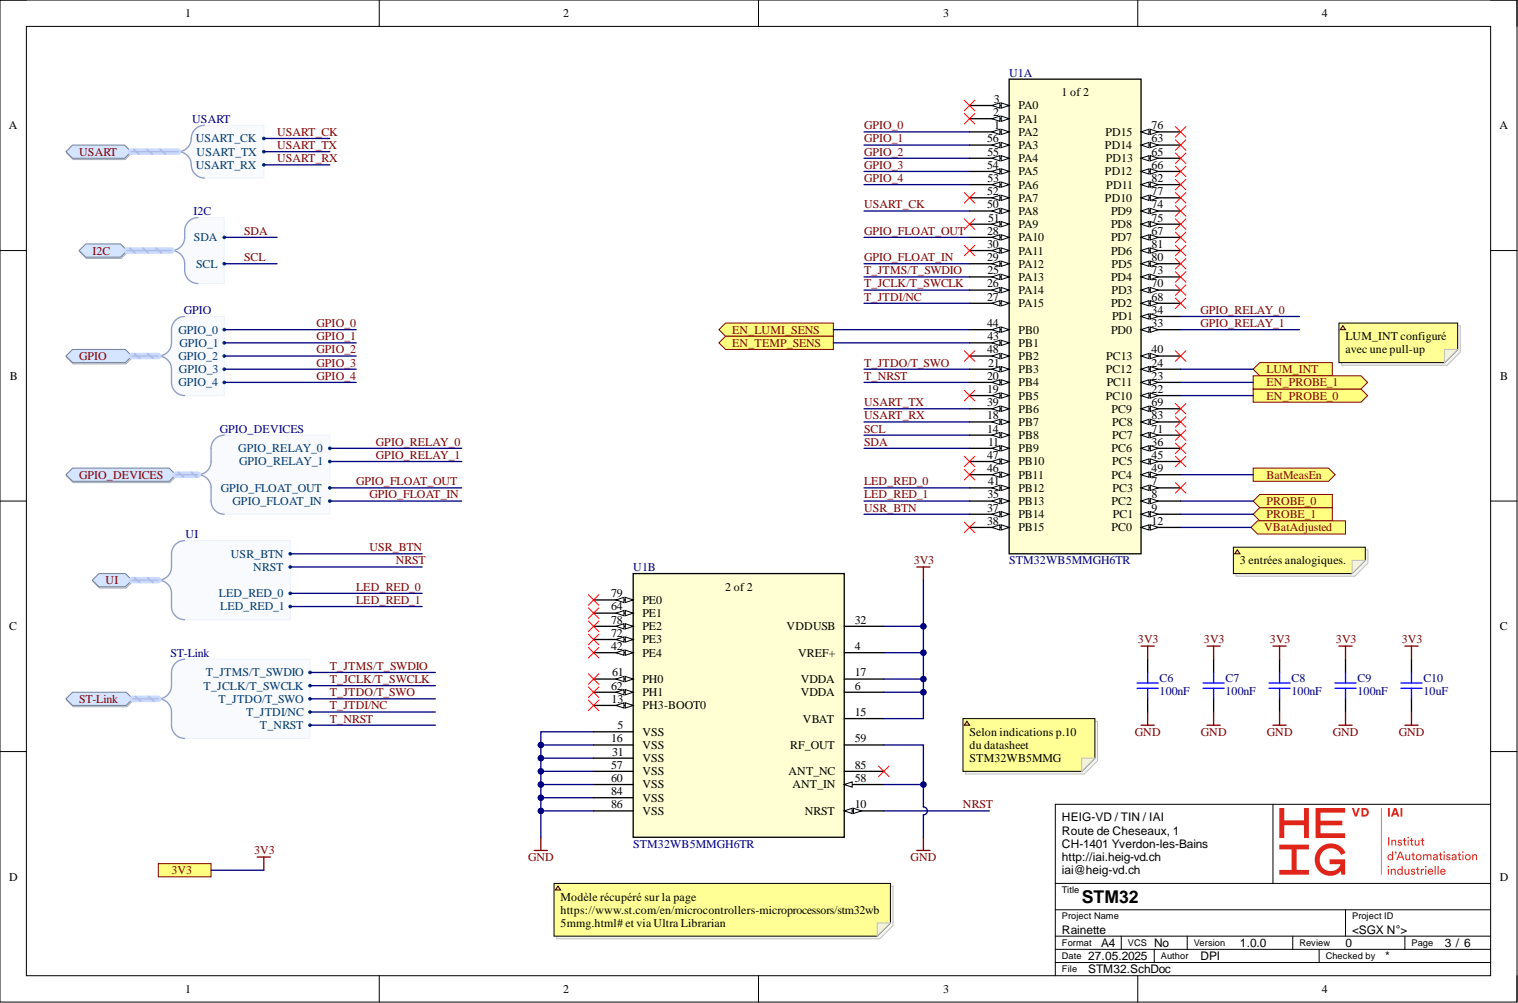
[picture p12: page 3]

LUM_INT configuré
avec une pull-up

HEIG-VD / TIN / IAI
Route de Cheseaux, 1
CH-1401 Yverdon-les-Bains
http://iai.heig-vd.ch
iai@heig-vd.ch
STM32

Modèle récupéré sur la page
https://www.st.com/en/microcontrollers-microprocessors/stm32wb
5mmg.html# et via Ultra Librarian

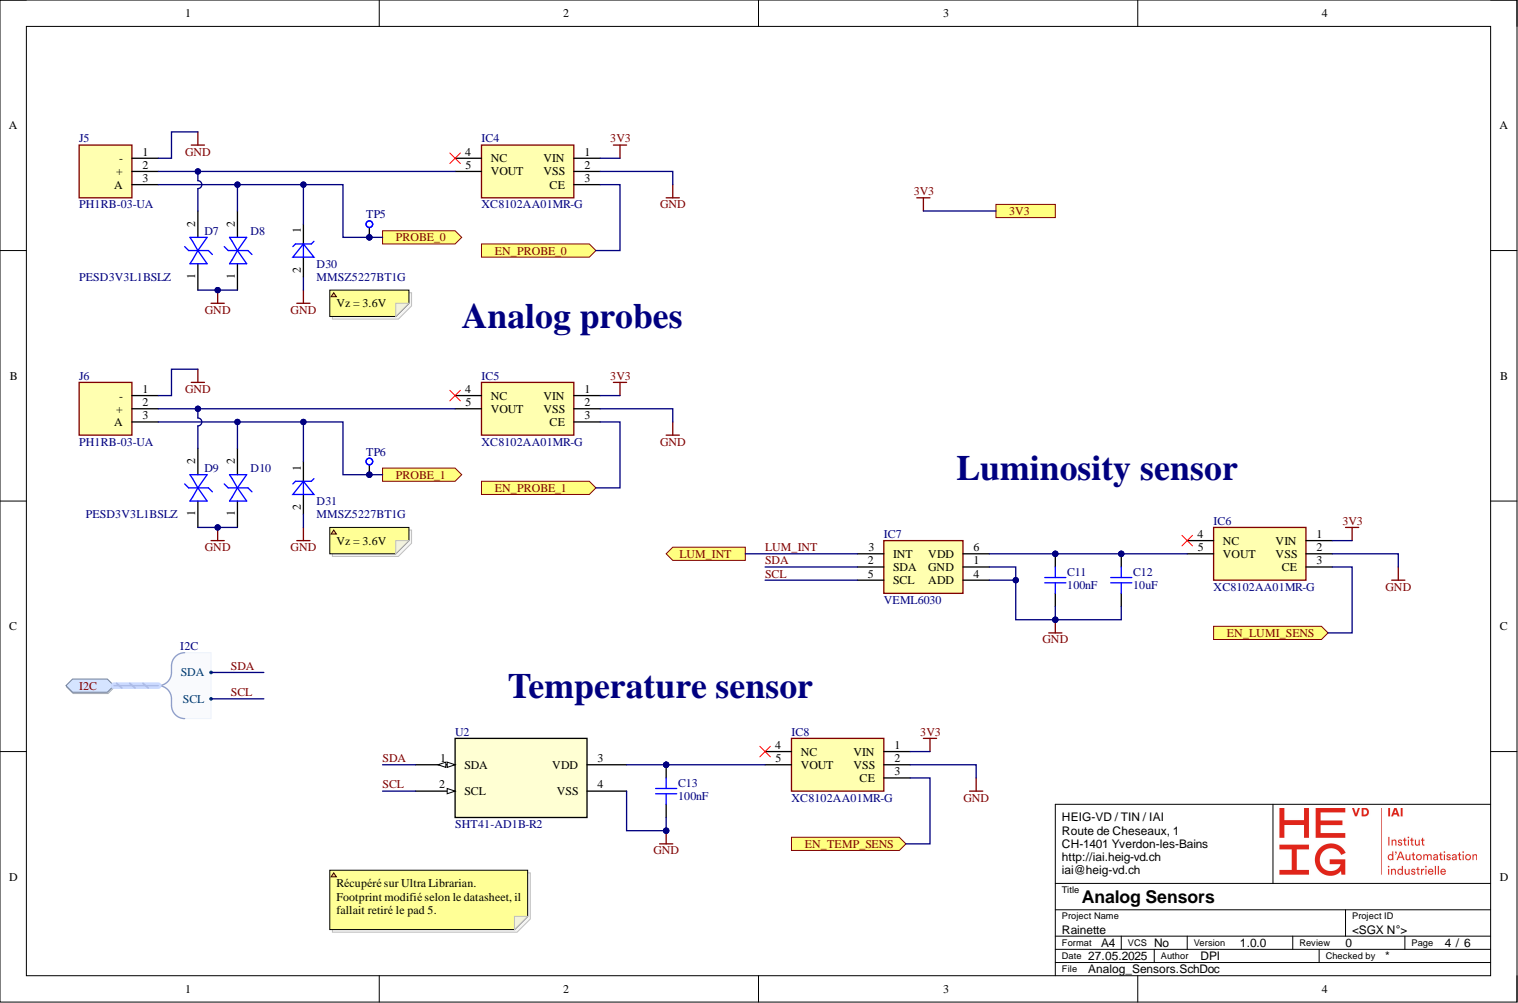
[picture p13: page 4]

HEIG-VD / TIN / IAI
Route de Cheseaux, 1
CH-1401 Yverdon-les-Bains
http://iai.heig-vd.ch
iai@heig-vd.ch
Analog Sensors

Récupéré sur Ultra Librarian.
Footprint modifié selon le datasheet, il
fallait retiré le pad 5.

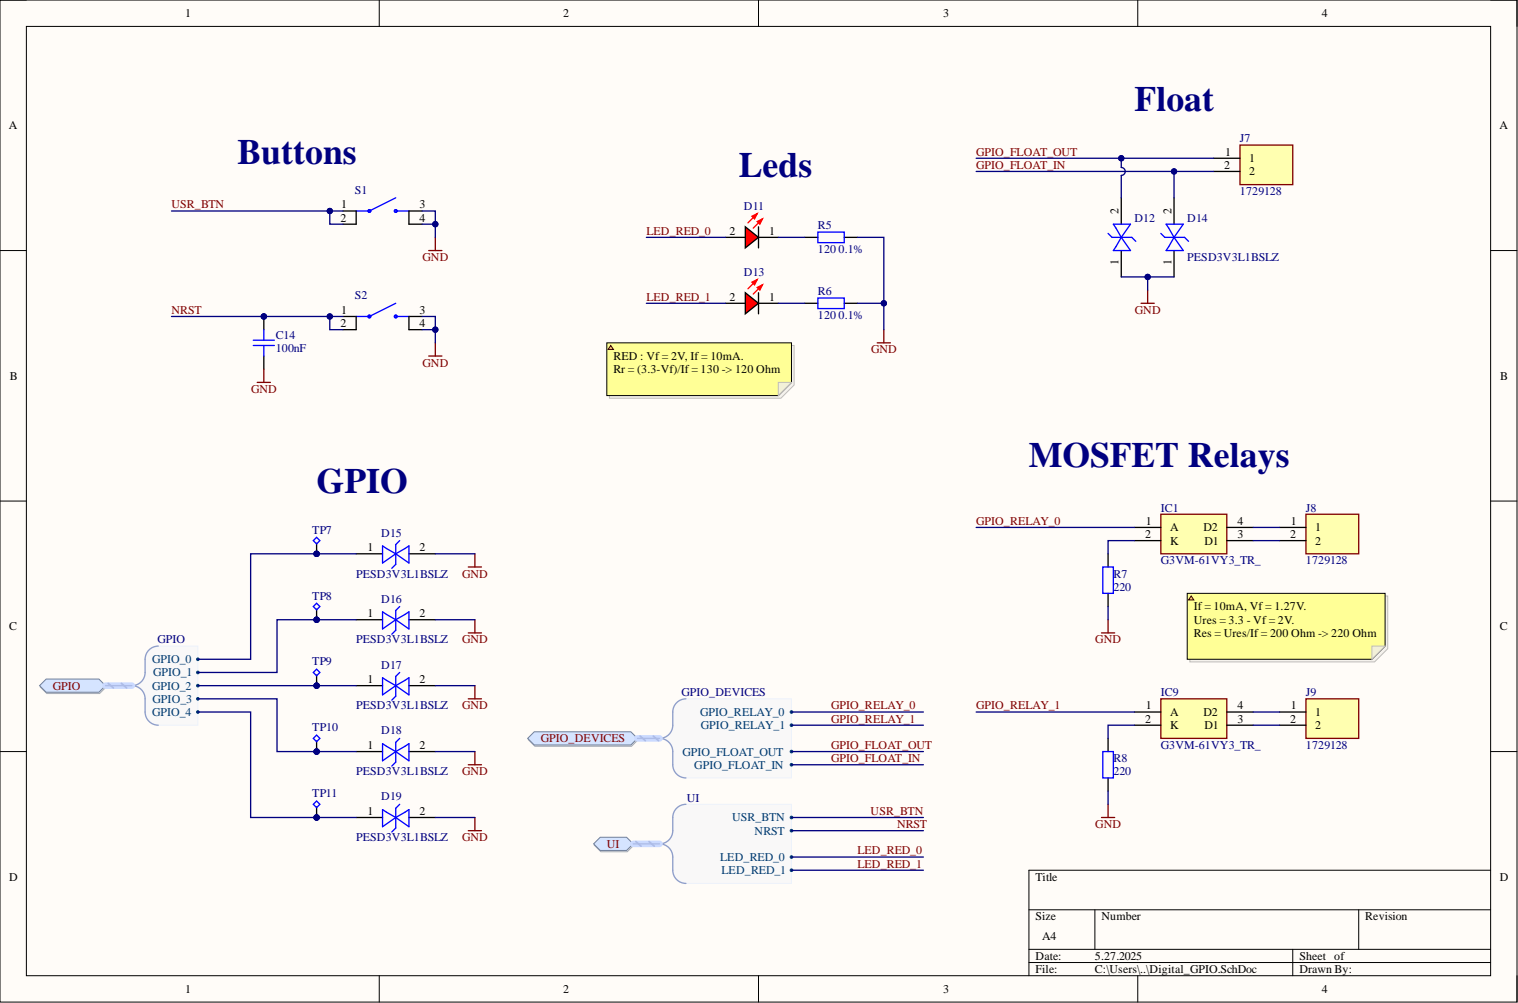
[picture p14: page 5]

RED : Vf = 2V, If = 10mA.
Rr = (3.3-Vf)/If = 130 -> 120 Ohm

Ures = 3.3 - Vf = 2V.
Res = Ures/If = 200 Ohm -> 220 Ohm

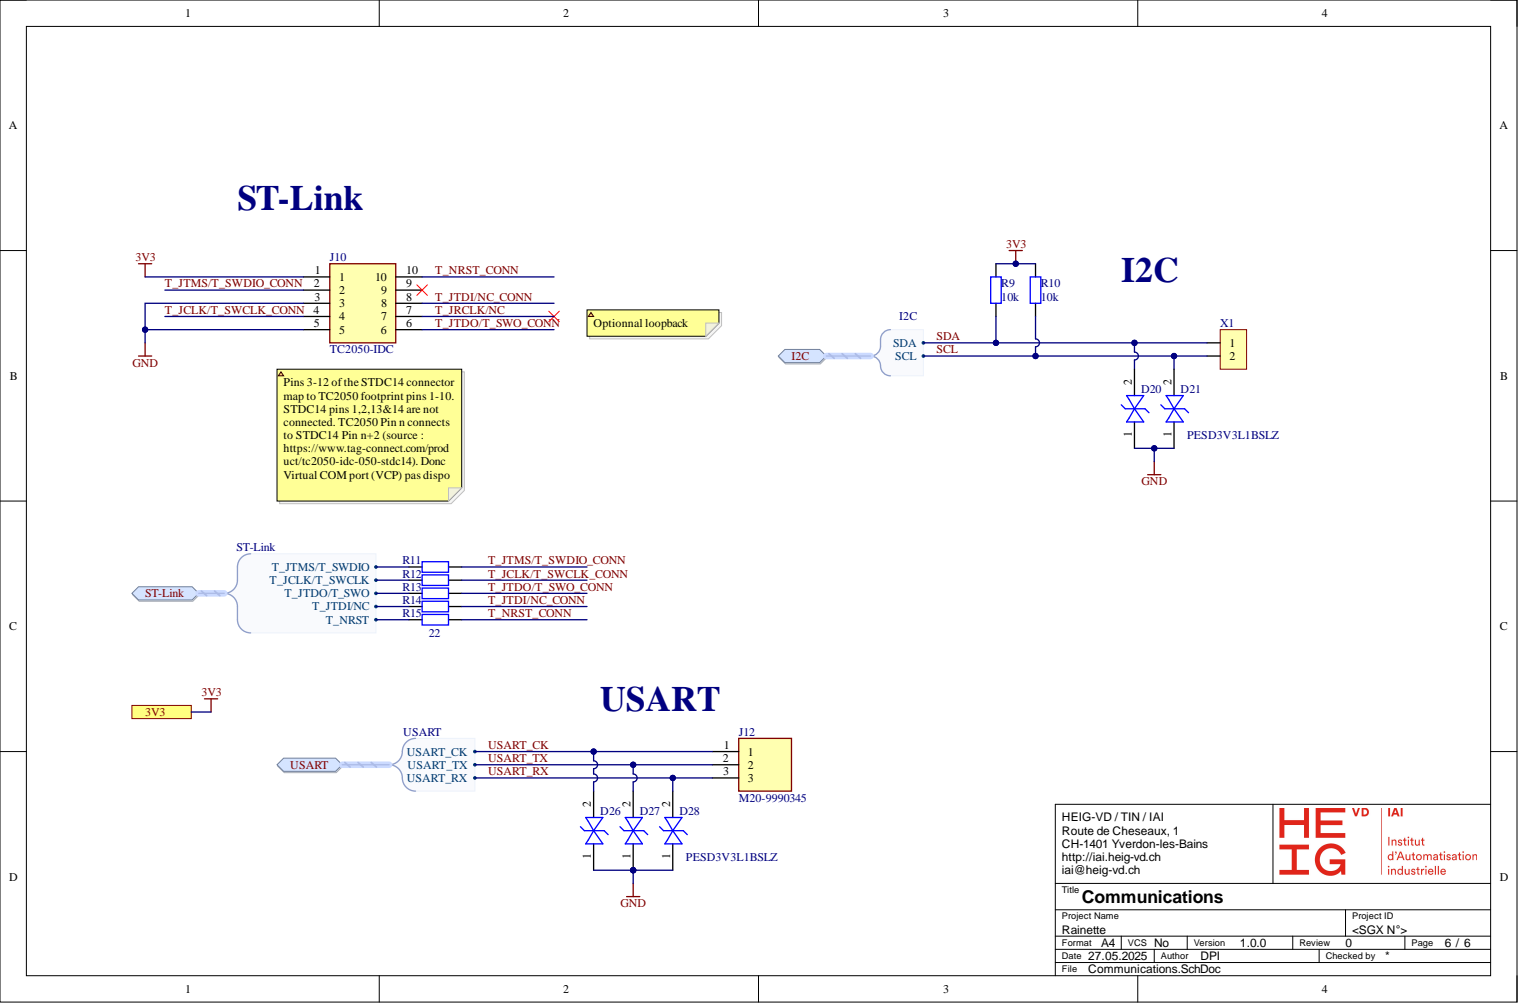
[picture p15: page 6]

Pins 3-12 of the STDC14 connector
map to TC2050 footprint pins 1-10.
STDC14 pins 1,2,13&14 are not
connected. TC2050 Pin n connects
to STDC14 Pin n+2 (source :
https://www.tag-connect.com/prod
uct/tc2050-idc-050-stdc14). Donc
Virtual COM port (VCP) pas dispo

HEIG-VD / TIN / IAI
Route de Cheseaux, 1
CH-1401 Yverdon-les-Bains
http://iai.heig-vd.ch
iai@heig-vd.ch
Communications







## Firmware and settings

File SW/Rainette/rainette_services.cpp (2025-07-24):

//  rainette_services.cpp
//  project : Rainette
//  author : Damien Pomelli 
//  last modified : 2025-07-24

#include "rainette_services.h"

GeneralService::GeneralService(BLE &arg_ble) : 
    ble(arg_ble),
    batt_detect_val(false),
    start_meas_val(false),
    end_of_comm_val(false),
    ping_pong_val(false),

    batt_detect_char(
        BATT_DETECT_CHAR_UUID,
        &batt_detect_val,
        GattCharacteristic::BLE_GATT_CHAR_PROPERTIES_READ |
        GattCharacteristic::BLE_GATT_CHAR_PROPERTIES_NOTIFY
    ),
    start_meas_char(
        START_MEAS_CHAR_UUID,
        &start_meas_val,
        GattCharacteristic::BLE_GATT_CHAR_PROPERTIES_READ |
        GattCharacteristic::BLE_GATT_CHAR_PROPERTIES_WRITE |
        GattCharacteristic::BLE_GATT_CHAR_PROPERTIES_NOTIFY
    ),
    end_of_comm_char(
        END_OF_COMM_CHAR_UUID,
        &end_of_comm_val,
        GattCharacteristic::BLE_GATT_CHAR_PROPERTIES_READ |
        GattCharacteristic::BLE_GATT_CHAR_PROPERTIES_WRITE |
        GattCharacteristic::BLE_GATT_CHAR_PROPERTIES_NOTIFY
    ),
    ping_pong_char(
        PING_PONG_CHAR_UUID,
        &ping_pong_val,
        GattCharacteristic::BLE_GATT_CHAR_PROPERTIES_READ |
        GattCharacteristic::BLE_GATT_CHAR_PROPERTIES_WRITE |
        GattCharacteristic::BLE_GATT_CHAR_PROPERTIES_NOTIFY
    ),

    charTable{  &batt_detect_char, 
                &start_meas_char, 
                &end_of_comm_char, 
                &ping_pong_char 
    },
    service(GENERAL_SERVICES_UUID, charTable, sizeof(charTable) / sizeof(charTable[0]))
{

}

void GeneralService::resetAndAddService()
{
    batt_detect_val = false,
    start_meas_val = false;
    end_of_comm_val = false;
    ping_pong_val = false;
    ble.gattServer().addService(service);
}

void GeneralService::writeBattDetect(bool new_batt_detect)
{
    batt_detect_val = new_batt_detect;
    ble.gattServer().write(
        batt_detect_char.getValueHandle(),
        (uint8_t *)&batt_detect_val,
        sizeof(batt_detect_val)
    );
}

bool GeneralService::readStartMeas()
{
    uint8_t start_meas_resp = 0;
    uint16_t length = sizeof(start_meas_resp);
    ble.gattServer().read(
        start_meas_char.getValueHandle(),
        (uint8_t *)&start_meas_resp,
        &length
    );
    return (start_meas_resp != 0);
}

void GeneralService::writeStartMeas(bool new_start_meas)
{
    start_meas_val = new_start_meas;
    ble.gattServer().write(
        start_meas_char.getValueHandle(),
        (uint8_t *)&start_meas_val,
        sizeof(start_meas_val)
    );
}

bool GeneralService::readEndOfComm()
{
    uint8_t end_of_comm_resp = 0;
    uint16_t length = sizeof(end_of_comm_resp);
    ble.gattServer().read(
        end_of_comm_char.getValueHandle(),
        (uint8_t *)&end_of_comm_resp,
        &length
    );
    return (end_of_comm_resp != 0);
}

void GeneralService::writeEndOfComm(bool new_end_of_comm)
{
    end_of_comm_val = new_end_of_comm;
    ble.gattServer().write(
        end_of_comm_char.getValueHandle(),
        (uint8_t *)&end_of_comm_val,
        sizeof(end_of_comm_val)
    );
}

bool GeneralService::readPingPong()
{
    uint8_t ping_pong_resp = 0;
    uint16_t length = sizeof(ping_pong_resp);
    ble.gattServer().read(
        ping_pong_char.getValueHandle(),
        (uint8_t *)&ping_pong_resp,
        &length
    );
    return (ping_pong_resp != 0);
}

void GeneralService::writePingPong(bool new_ping_pong)
{
    ping_pong_val = new_ping_pong;
    ble.gattServer().write(
        ping_pong_char.getValueHandle(),
        (uint8_t *)&ping_pong_val,
        sizeof(ping_pong_val)
    );
}

GattAttribute::Handle_t GeneralService::getBattDetectHandle()
{
    return batt_detect_char.getValueHandle();
}

GattAttribute::Handle_t GeneralService::getStartMeasHandle()
{
    return start_meas_char.getValueHandle();
}

GattAttribute::Handle_t GeneralService::getEndOfCommHandle()
{
    return end_of_comm_char.getValueHandle();
}

GattAttribute::Handle_t GeneralService::getPingPongHandle()
{
    return ping_pong_char.getValueHandle();
}

AnalogService::AnalogService(BLE &arg_ble) :
    ble(arg_ble),
    probe0_val(0),
    probe1_val(0),
    lumi_val(0),
    temp_val(0),
    humi_val(0),
    batt_val(0),

    probe0_char(
        PROBE0_CHAR_UUID,
        &probe0_val,
        GattCharacteristic::BLE_GATT_CHAR_PROPERTIES_READ |
        GattCharacteristic::BLE_GATT_CHAR_PROPERTIES_NOTIFY
    ),
    probe1_char(
        PROBE1_CHAR_UUID,
        &probe1_val,
        GattCharacteristic::BLE_GATT_CHAR_PROPERTIES_READ |
        GattCharacteristic::BLE_GATT_CHAR_PROPERTIES_NOTIFY
    ),
    lumi_char(
        LUMI_CHAR_UUID,
        &lumi_val,
        GattCharacteristic::BLE_GATT_CHAR_PROPERTIES_READ |
        GattCharacteristic::BLE_GATT_CHAR_PROPERTIES_NOTIFY
    ),
    temp_char(
        TEMP_CHAR_UUID,
        &temp_val,
        GattCharacteristic::BLE_GATT_CHAR_PROPERTIES_READ |
        GattCharacteristic::BLE_GATT_CHAR_PROPERTIES_NOTIFY
    ),
    humi_char(
        HUMI_CHAR_UUID,
        &humi_val,
        GattCharacteristic::BLE_GATT_CHAR_PROPERTIES_READ |
        GattCharacteristic::BLE_GATT_CHAR_PROPERTIES_NOTIFY
    ),
    batt_char(
        BATT_CHAR_UUID,
        &batt_val,
        GattCharacteristic::BLE_GATT_CHAR_PROPERTIES_READ |
        GattCharacteristic::BLE_GATT_CHAR_PROPERTIES_NOTIFY
    ),

    charTable{  &probe0_char,
                &probe1_char,
                &lumi_char,
                &temp_char,
                &humi_char,
                &batt_char
    },
    service(ANALOG_SERVICES_UUID, charTable, sizeof(charTable) / sizeof(charTable[0]))
{

}

void AnalogService::resetAndAddService()
{
    probe0_val = 0,
    probe1_val = 0,
    lumi_val = 0,
    temp_val = 0,
    humi_val = 0,
    batt_val = 0,
    ble.gattServer().addService(service);
}

void AnalogService::writeProbe0(uint16_t new_probe0)
{
    probe0_val = new_probe0;
    ble.gattServer().write(
        probe0_char.getValueHandle(),
        (uint8_t *)&probe0_val,
        sizeof(probe0_val)
    );
}

void AnalogService::writeProbe1(uint16_t new_probe1)
{
    probe1_val = new_probe1;
    ble.gattServer().write(
        probe1_char.getValueHandle(),
        (uint8_t *)&probe1_val,
        sizeof(probe1_val)
    );
}

void AnalogService::writeLumi(uint16_t new_lumi)
{
    lumi_val = new_lumi;
    ble.gattServer().write(
        lumi_char.getValueHandle(),
        (uint8_t *)&lumi_val,
        sizeof(lumi_val)
    );
}

void AnalogService::writeTemp(uint16_t new_temp)
{
    temp_val = new_temp;
    ble.gattServer().write(
        temp_char.getValueHandle(),
        (uint8_t *)&temp_val,
        sizeof(temp_val)
    );
}

void AnalogService::writeHumi(uint16_t new_humi)
{
    humi_val = new_humi;
    ble.gattServer().write(
        humi_char.getValueHandle(),
        (uint8_t *)&humi_val,
        sizeof(humi_val)
    );
}
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

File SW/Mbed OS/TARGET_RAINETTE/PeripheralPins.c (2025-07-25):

/* mbed Microcontroller Library
 * SPDX-License-Identifier: BSD-3-Clause
 ******************************************************************************
 *
 * Copyright (c) 2016-2025 STMicroelectronics.
 * All rights reserved.
 *
 * This software component is licensed by ST under BSD 3-Clause license,
 * the "License"; You may not use this file except in compliance with the
 * License. You may obtain a copy of the License at:
 *                        opensource.org/licenses/BSD-3-Clause
 *
 ******************************************************************************
 *
 * Automatically generated from STM32CubeMX/db/mcu/STM32WB5MMGHx.xml
 */

#include "PeripheralPins.h"
#include "mbed_toolchain.h"

//==============================================================================
// Notes
//
// - The pins mentioned Px_y_ALTz are alternative possibilities which use other
//   HW peripheral instances. You can use them the same way as any other "normal"
//   pin (i.e. PwmOut pwm(PA_7_ALT0);). These pins are not displayed on the board
//   pinout image on mbed.org.
//
// - The pins which are connected to other components present on the board have
//   the comment "Connected to xxx". The pin function may not work properly in this
//   case. These pins may not be displayed on the board pinout image on mbed.org.
//   Please read the board reference manual and schematic for more information.
//
// - Warning: pins connected to the default STDIO_UART_TX and STDIO_UART_RX pins are commented
//   See https://os.mbed.com/teams/ST/wiki/STDIO for more information.
//
//==============================================================================


//*** ADC ***

MBED_WEAK const PinMap PinMap_ADC[] = {
    {PA_0,       ADC_1, STM_PIN_DATA_EXT(STM_MODE_ANALOG, GPIO_NOPULL, 0, 5, 0)}, // ADC1_IN5
    {PA_1,       ADC_1, STM_PIN_DATA_EXT(STM_MODE_ANALOG, GPIO_NOPULL, 0, 6, 0)}, // ADC1_IN6
    {PA_2,       ADC_1, STM_PIN_DATA_EXT(STM_MODE_ANALOG, GPIO_NOPULL, 0, 7, 0)}, // ADC1_IN7
    {PA_3,       ADC_1, STM_PIN_DATA_EXT(STM_MODE_ANALOG, GPIO_NOPULL, 0, 8, 0)}, // ADC1_IN8
    {PA_4,       ADC_1, STM_PIN_DATA_EXT(STM_MODE_ANALOG, GPIO_NOPULL, 0, 9, 0)}, // ADC1_IN9
    {PA_5,       ADC_1, STM_PIN_DATA_EXT(STM_MODE_ANALOG, GPIO_NOPULL, 0, 10, 0)}, // ADC1_IN10
    {PA_6,       ADC_1, STM_PIN_DATA_EXT(STM_MODE_ANALOG, GPIO_NOPULL, 0, 11, 0)}, // ADC1_IN11
    {PA_7,       ADC_1, STM_PIN_DATA_EXT(STM_MODE_ANALOG, GPIO_NOPULL, 0, 12, 0)}, // ADC1_IN12
    {PA_8,       ADC_1, STM_PIN_DATA_EXT(STM_MODE_ANALOG, GPIO_NOPULL, 0, 15, 0)}, // ADC1_IN15
    {PA_9,       ADC_1, STM_PIN_DATA_EXT(STM_MODE_ANALOG, GPIO_NOPULL, 0, 16, 0)}, // ADC1_IN16
    {PC_0,       ADC_1, STM_PIN_DATA_EXT(STM_MODE_ANALOG, GPIO_NOPULL, 0, 1, 0)}, // ADC1_IN1
    {PC_1,       ADC_1, STM_PIN_DATA_EXT(STM_MODE_ANALOG, GPIO_NOPULL, 0, 2, 0)}, // ADC1_IN2
    {PC_2,       ADC_1, STM_PIN_DATA_EXT(STM_MODE_ANALOG, GPIO_NOPULL, 0, 3, 0)}, // ADC1_IN3
    {PC_3,       ADC_1, STM_PIN_DATA_EXT(STM_MODE_ANALOG, GPIO_NOPULL, 0, 4, 0)}, // ADC1_IN4
    {PC_4,       ADC_1, STM_PIN_DATA_EXT(STM_MODE_ANALOG, GPIO_NOPULL, 0, 13, 0)}, // ADC1_IN13
    {PC_5,       ADC_1, STM_PIN_DATA_EXT(STM_MODE_ANALOG, GPIO_NOPULL, 0, 14, 0)}, // ADC1_IN14
    {NC, NC, 0}
};

// !!! SECTION TO BE CHECKED WITH DEVICE REFERENCE MANUAL
MBED_WEAK const PinMap PinMap_ADC_Internal[] = {
//     {ADC_TEMP,   ADC_1,    STM_PIN_DATA_EXT(STM_MODE_ANALOG, GPIO_NOPULL, 0, 16, 0)},
//     {ADC_VREF,   ADC_1,    STM_PIN_DATA_EXT(STM_MODE_ANALOG, GPIO_NOPULL, 0, 17, 0)},
//     {ADC_VBAT,   ADC_1,    STM_PIN_DATA_EXT(STM_MODE_ANALOG, GPIO_NOPULL, 0, 18, 0)},
    {NC, NC, 0}
};

//*** I2C ***

MBED_WEAK const PinMap PinMap_I2C_SDA[] = {
    {PA_10,      I2C_1, STM_PIN_DATA(STM_MODE_AF_OD, GPIO_NOPULL, GPIO_AF4_I2C1)},
    {PB_4,       I2C_3, STM_PIN_DATA(STM_MODE_AF_OD, GPIO_NOPULL, GPIO_AF4_I2C3)},
    {PB_7,       I2C_1, STM_PIN_DATA(STM_MODE_AF_OD, GPIO_NOPULL, GPIO_AF4_I2C1)},
    {PB_9,       I2C_1, STM_PIN_DATA(STM_MODE_AF_OD, GPIO_NOPULL, GPIO_AF4_I2C1)},
    {PB_11,      I2C_3, STM_PIN_DATA(STM_MODE_AF_OD, GPIO_NOPULL, GPIO_AF4_I2C3)},
    {PB_14,      I2C_3, STM_PIN_DATA(STM_MODE_AF_OD, GPIO_NOPULL, GPIO_AF4_I2C3)},
    {PC_1,       I2C_3, STM_PIN_DATA(STM_MODE_AF_OD, GPIO_NOPULL, GPIO_AF4_I2C3)},
    {NC, NC, 0}
};

MBED_WEAK const PinMap PinMap_I2C_SCL[] = {
    {PA_7,       I2C_3, STM_PIN_DATA(STM_MODE_AF_OD, GPIO_NOPULL, GPIO_AF4_I2C3)},
    {PA_9,       I2C_1, STM_PIN_DATA(STM_MODE_AF_OD, GPIO_NOPULL, GPIO_AF4_I2C1)},
    {PB_6,       I2C_1, STM_PIN_DATA(STM_MODE_AF_OD, GPIO_NOPULL, GPIO_AF4_I2C1)},
    {PB_8,       I2C_1, STM_PIN_DATA(STM_MODE_AF_OD, GPIO_NOPULL, GPIO_AF4_I2C1)},
    {PB_10,      I2C_3, STM_PIN_DATA(STM_MODE_AF_OD, GPIO_NOPULL, GPIO_AF4_I2C3)},
    {PB_13,      I2C_3, STM_PIN_DATA(STM_MODE_AF_OD, GPIO_NOPULL, GPIO_AF4_I2C3)},
    {PC_0,       I2C_3, STM_PIN_DATA(STM_MODE_AF_OD, GPIO_NOPULL, GPIO_AF4_I2C3)},
    {NC, NC, 0}
};

//*** PWM ***
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
